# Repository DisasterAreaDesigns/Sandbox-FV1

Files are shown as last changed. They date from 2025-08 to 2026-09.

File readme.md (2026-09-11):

# FV-1 Sandbox
FV-1 Sandbox is a self-contained open-source development platform for the Spin FV-1 digital signal processing (DSP) integrated circuit.  

## Background:
The Spin Semiconductor FV-1 IC was developed by Alesis alumni Keith Barr and Frank Thomson.  It features an integrated architecture with built-in analog-to-digital and digital-to-analog converters, memory, and processing core.  It requires only a few external components to operate, and can run user programs from an inexpensive serial EEPROM.  It has been used in hundreds of different pedals and devices, with many hundreds of thousands of units in service.

## Why Are We Doing This?
The FV-1 has seven built-in programs that cover a wide range of effects, but most designers leverage the custom code capabilities of the chip.  The Fv-1 is programmed in SpinASM, a proprietary assembly language.  Spin provided a free integrated development environment for Windows computers called SpinASM IDE.  This interfaces with a development board fitted with a Cypress PSoC microcontroller functioning as a USB interface.  The IDE allows for code editing, rapid auditioning of DSP algorithms on the development board, and production programming using multi-algorithm .SPJ Spin Project files.  No MacOS or Linux programming tools were made available, and SpinASM also had issues running on newer versions of Windows.  A patch was released to fix compatibility issues under Windows 7, and this version (1.1.31) works with most Windows 10 and Windows 11 systems.  The IDE does also run under Windows for ARM, but support for the PSoC-based development board is broken due to driver issues.

Our intention is to create a complete toolchain that can run on any modern computer that interfaces with a high-quality hardware platform for deploying algorithms.  To this end, we have created an open-source assembler that runs in a web browser and a hardware platform that interfaces with an inexpensive RP2040 microcontroller for programming.  The hardware platform may be assembled without the microcontroller for higher-quantity production use, and the RP2040 programmer may be used in conjunction with either a TagConnect programming cable or pin sockets on the PCB for production programming.

## What Did We Do?
We've been using [asfv1](https://github.com/ndf-zz/asfv1), an open-source assembler for FV-1 designed by Nathan Fraser.  It works great but requires a few steps to deploy as part of a larger toolchain.  It works with Sublime Text or Notepad++ to create a DIY development environment, but it's still a lot of work for a new user.  So we decided to build a one-stop shop!

We patched up some bugs we found, added some quality-of-life improvements, and ported the whole thing from Python to JavaScript so we could run it in a browser.  There's a pretty decent code editor using Monaco, an assembler, and a one-button deployment to the Sandbox hardware.

The hardware is very simple, incorporating a high-quality analog front-end that reduces out-of-band and clock noise from the FV-1.  It's full stereo, features three user potentiometer controls, and two toggle switches for selecting one of six possible algorithms.  It also uses program zero to bypass the effect, allowing stereo switching without any external hardware or relays, albeit at the cost of higher noise floor and a slight delay from the DSP ADC+DAC conversions.

Programming is accomplished using the aforementioned RP2040 board - we've used a Waveshare RP2040 Zero for its compact form factor and handy USB-C port, but clones of this part or other variations may also work.  the RP2040 code is implemented in CircuitPython for ease of deployment and modification.  To program a new algorithm on the Sandbox EEPROM, simply copy an assembled .HEX or .BIN file to the RP2040 CIRCUITPY or SANDBOX removable drive.  Name the program 0.HEX to program algorithm zero, 1.HEX for program 1, and so on.  Adding any other named .BIN or .HEX file will write program #3, which is the program accessed if no toggle switches are assembled to the Sandbox PCBA.

We've also added an FV-1 simulator to the web app.  The assembled program runs through a software model of the chip at its native 32.768 kHz, so you can audition an algorithm on a test tone, an audio file, or live input before you ever program the hardware.  The three pot controls are on screen, and each successful build reloads into the simulator while it plays.  Two indicator lamps follow `REG30` and `REG31`.  The simulator models accumulator saturation and the FV-1's companded delay memory, and its LFO rates and depths follow the equations in Spin's application note AN-0001.  Chorus interpolation is approximated, so always confirm a design on real hardware.

The simulator can also be played from a MIDI controller plugged into your computer.  Press **Enable MIDI** in the simulator panel, allow the browser's MIDI prompt, and pick an input and channel.  `CC50`, `CC51` and `CC52` sweep POT0, POT1 and POT2, and `CC102` switches the effect, with `0-63` bypassed and `64-127` engaged.  MIDI moves the same controls the sliders do, at the full 128 steps a control change carries, so a program cannot tell the difference between a fader and a mouse.  Note that the Sandbox pedal itself has no MIDI input - this drives the simulator only.

The simulator can be watched as well as heard.  **Open register viewer**, under **Debug Tools** in the simulator panel, opens a second window (floating above the editor where the browser allows it, with an **Always on top** switch in its header) showing `ACC`, the audio in and out, the pots, the LFOs and `REG0`-`REG31` as the program runs, each as its S.23 value and the 24-bit word behind it, and named after the `EQU` lines in your source.  Click a register there to plot it over time - an audio-rate signal shows as its envelope and an LFO as its shape.  **ACC trace in editor** writes the accumulator after every instruction at the end of its line, live: a `SKP` says whether it was taken, the lines it jumped over say so, and a line whose result had to be clamped shows how often that happens.  The FV-1 runs every instruction every sample, so one pass is a complete trace and there is nothing to step through to see it.

When there is, the **Debug** section halts the simulator and steps it.  **Halt** freezes the core at the end of the current sample; **Step** runs one instruction, **Sample** runs the rest of the pass, and **Run to line** goes on until that line is next, with the editor following, the trace showing this pass up to the halt, and the register viewer updating on every step.  Breakpoints are conditions rather than places, since a bare line would trip on the first sample: click the margin left of a line number for a line breakpoint and give it a first run or a sample number, or halt on a clip, a `SKP` going one way, or `ACC` or a register crossing a value.  While halted the output is silent and the input is held at the halted sample; **Resume** carries on from wherever the stepping got to.

So it's a web app and a pedal.  Hook 'em up and write some code!

## Running the Assembler Locally
The web app needs to be served over http - opening `Assembler/index.html` directly as a `file://` page will not work.  Browsers block the audio engine the simulator depends on from `file://` origins, and the directory and serial access used to talk to the hardware need a secure context too.  `localhost` counts as secure, so any static file server will do:

```
python3 -m http.server 8000 --directory Assembler
```

Then open <http://localhost:8000> in Chrome or Edge.  If you prefer Node, `npx serve Assembler` works the same way.

Chrome or Edge are required for programming hardware and selecting folders, since Firefox and Safari do not implement the File System Access and Web Serial APIs.  The simulator itself works in any browser with AudioWorklet support, and its MIDI control works in Chrome, Edge and Firefox - Safari has no Web MIDI.

## What's In This Repo?
* **ASFV1 Source:**  copies of the Python source for asfv1, the reference assembler this one is checked against
* **Assembler:**  JavaScript Web Application for assembling FV-1 programs, including an in-browser FV-1 simulator (`fv1-emu.js` / `fv1-sim.js`) with MIDI control (`fv1-midi.js`), a register viewer (`fv1-regs.js`), an ACC trace in the editor (`fv1-trace.js`) and a halt-and-step debugger with conditional breakpoints (`fv1-debug.js`)
* **Firmware**  CircuitPython code for the RP2040 Zero program module
* **spin-test**  Puppeteer scripts and sample FV-1 programs for testing the assembler: `npm run test:roundtrip` for the assembler and simulator as a pair, `npm run test:emu` for the DSP core, `npm run test:midi` for the simulator's MIDI control, and `npm run test:page` for the editor's unsaved-changes guard
* **Hardware**  Schematic and PCB files for Sandbox pedal hardware

## What Can I Do With All This?
We've released this project and all associated tools under the [MIT License.](https://www.tldrlegal.com/license/mit-license)  This means that you can use the tools and information in this repository for anything you want, as long as you inform your users / customers / clients that you got it from us.  You can modify or change anything here to suit your purposes, and you can make products that you sell for profit.  You can even close your sources, so that what's in your product or project is private.  You just have to credit us as shown in our [license file.](https://github.com/DisasterAreaDesigns/Sandbox-FV1/blob/main/LICENSE)  An example of what that looks like can be found in our [Third Party Notices](https://github.com/DisasterAreaDesigns/Sandbox-FV1/blob/main/ThirdPartyNotices.txt) file.

Any projects you create with these tools belong to you.  If you write your own code to process audio with this project, that code is under your copyright and is yours to do with what you wish.  If you use someone else's DSP algorithms, that use will be subject to *their* license terms, and we're not able to help you sort that out.  TL:DR you can do whatever you want with this repo, just give us credit.

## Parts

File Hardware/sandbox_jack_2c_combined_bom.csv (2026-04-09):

Comment | Designator | Footprint | LCSC Part # | Type
 | JP1 | 1X05 |  | THT
DC_TRS | J2 | JACK_DC_PC-MOUNT_2.1MM_NO-KEEPOUT |  | THT
STEREOSW3NOMOUNT | J1 J3 | NEUTRIK-NRJ6HF-NOMOUNT |  | THT

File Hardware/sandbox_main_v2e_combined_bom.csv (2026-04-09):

Comment | Designator | Footprint | LCSC Part # | Type
 | FS | 1X02 |  | THT
 | I2C | 1X04 |  | THT
 | JP1 | 1X07 |  | THT
 | LED1 | DUOLED-C-5MM |  | THT
 | PWR | 1X03 |  | THT
 | SW100 SW101 | 320-916 |  | THT
 | TC1 | TC2030-MCP-NL |  | SMD
0 | R1 | R0805 |  | SMD
0.1uF | C1 C2 C20 C22 C32 | C0805K |  | SMD
0.047uF | C29 C30 | C1206K |  | SMD
1M | R33 R35 R36 R38 | R0805 |  | SMD
1k | R7 R8 | R0805 |  | SMD
1uF | C33 | C0805K |  | SMD
2.2nF | C12 C13 C16 C21 | C0805K |  | SMD
2SK209-GR | Q1 Q2 | SOT-23 |  | SMD
4.7K | R31 | R0805 |  | SMD
10k | R2 R3 R4 R6 R11 R12 R17 R18 R25 R26 R32 R34 R37 | R0805 |  | SMD
10kB | POT0 POT1 POT2 | POT_9MM_PACK_SM |  | THT
10uF | C7 C9 C10 C11 C24 C25 C26 C27 | CT3216 |  | SMD
10uf | C5 C6 | C0805K |  | SMD
15pF | C3 | C0805K |  | SMD
22k | R9 R10 R13 R14 R15 R16 R21 R22 R40 | R0805 |  | SMD
24LC32ASN | IC1 | SO-08 |  | SMD
32.768kHz | X2 | CRYSTAL-SMD-3.2X1.5MM |  | SMD
47pF | C18 C23 | C0805K |  | SMD
47uF | C8 C15 | C1206K |  | SMD
56k | R19 R20 R23 R24 R39 | R0805 |  | SMD
68pF | C17 C19 | C0805K |  | SMD
74HC08 | IC2 | SO14 |  | SMD
74HC4024M | IC6 | SO14 |  | SMD
78L33SMD | VR1 | SO08 |  | SMD
100 | R5 | R0805 |  | SMD
100k | R27 R28 | R0805 |  | SMD
100uF | C4 C14 C31 | C1206K |  | SMD
220uF | C28 | PANASONIC_D |  | SMD
560 | R29 R30 | R0805 |  | SMD
628 | H1 | 628 |  | THT
BAS40 | D1 D2 | SOT23-R |  | SMD
DSIC02LSGET | SW1 | CTS-219-02 |  | SMD
NJM2100 | IC5 | SO08 |  | SMD
SPINFV-1 | IC3 | SOIC-28 |  | SMD
TL072D | IC4 | SO08 |  | SMD

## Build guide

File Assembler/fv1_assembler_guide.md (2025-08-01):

# FV-1 DSP Assembler Web App Guide

## Overview

This web application is a JavaScript port of an assembler for the Spin Semiconductor FV-1 digital signal processor (DSP). The FV-1 is a specialized chip commonly used in guitar effects pedals and audio processing applications. This assembler converts human-readable assembly code into machine code that can run on the FV-1 chip.

## Architecture

The application consists of three main components:

### 1. User Interface (HTML/CSS)
- **Code Editor**: A textarea with line numbers for writing assembly code
- **Options Panel**: Checkboxes for assembly options (clamping, SpinASM compatibility)
- **Control Buttons**: Assemble, Clear, Load File, Download outputs
- **Output Display**: Shows assembled machine code in Intel HEX format
- **Message Area**: Displays warnings and errors

### 2. FV1Assembler Class (JavaScript)
The core assembler implemented as a JavaScript class that handles:
- **Tokenization**: Breaking source code into meaningful symbols
- **Parsing**: Converting tokens into an abstract syntax tree
- **Code Generation**: Converting parsed instructions into machine code
- **Error Handling**: Tracking and reporting syntax/semantic errors

### 3. File I/O System
- **Input**: Load assembly files (.asm, .txt)
- **Output**: Download as Intel HEX (.hex) or binary (.bin) files

## How the Assembler Works

### Phase 1: Tokenization

The `tokenize()` method breaks source code into tokens:

```javascript
// Example: "LDAX ADCL" becomes ["LDAX", "ADCL"]
// "SOF 0.5, -0.2" becomes ["SOF", "0.5", ",", "-0.2"]
```

**Token Types:**
- `MNEMONIC`: Instruction names (LDAX, WRAX, SOF, etc.)
- `ASSEMBLER`: Directives (EQU, MEM)
- `NAME`: Labels and symbols
- `INTEGER`: Whole numbers (decimal, hex with $, binary with %)
- `FLOAT`: Decimal numbers
- `OPERATOR`: Arithmetic and punctuation (+, -, *, /, ,, etc.)
- `LABEL`: Names followed by colons

### Phase 2: Symbol Table Initialization

The assembler pre-populates a symbol table with:
- **Hardware registers**: POT0-POT2, ADCL, ADCR, DACL, DACR
- **General registers**: REG0-REG31
- **LFO references**: SIN0, SIN1, RMP0, RMP1
- **CHO operation types**: RDA, SOF, RDAL
- **Condition codes**: RUN, ZRC, ZRO, GEZ, NEG

### Phase 3: Parsing

The parser uses recursive descent to handle:

#### Expression Parsing
Supports full arithmetic with operator precedence:
- **Bitwise**: `|` (OR), `^` (XOR), `&` (AND)
- **Shift**: `<<`, `>>`
- **Arithmetic**: `+`, `-`, `*`, `/`, `//` (integer division)
- **Power**: `**`
- **Unary**: `-`, `~`, `!`

#### Fixed-Point Number Formats
The FV-1 uses various fixed-point formats:

- **S.10** (11-bit): 1 sign + 10 fractional bits, range -1.0 to ~0.999
- **S.15** (16-bit): 1 sign + 15 fractional bits, range -1.0 to ~0.999
- **S.23** (24-bit): 1 sign + 23 fractional bits, range -1.0 to ~0.999
- **S1.9** (11-bit): 1 sign + 1 integer + 9 fractional bits, range -2.0 to ~1.999
- **S1.14** (16-bit): 1 sign + 1 integer + 14 fractional bits, range -2.0 to ~1.999
- **S4.6** (11-bit): 1 sign + 4 integer + 6 fractional bits, range -16.0 to ~15.98

#### Instruction Parsing
Each instruction type has specific parsing rules:

**Memory Operations:**
```assembly
RDA DELAY, 0.5     ; Read from delay memory with coefficient
WRA DELAY, 0.8     ; Write to delay memory with coefficient
```

**Register Operations:**
```assembly
RDAX POT0, 0.5     ; Read register with multiplication
WRAX DACL, 1.0     ; Write to register with multiplication
```

**Mathematical Operations:**
```assembly
SOF 0.5, 0.1       ; Scale and offset: ACC = ACC * 0.5 + 0.1
LOG 0.8, 0.2       ; Logarithm with scaling
EXP 1.0, 0.0       ; Exponential with scaling
```

### Phase 4: Memory Management

#### Delay Memory Allocation
The `MEM` directive allocates delay memory:
```assembly
MEM DELAY 1024     ; Allocate 1024 samples
; Creates symbols:
;   DELAY   = base address
;   DELAY#  = end address (base + size)
;   DELAY^  = middle address (base + size/2)
```

#### Program Memory
- Maximum 128 instructions (4 bytes each = 512 bytes total)
- Instructions automatically padded to 128 with NOPs

### Phase 5: Code Generation

Each instruction is converted to a 32-bit machine code word:

```javascript
// Example: SOF 0.5, 0.1
// Opcode: 0b01101 (SOF)
// Multiplier: 0.5 * 2^14 = 8192 (S1.14 format)  
// Offset: 0.1 * 2^10 = 102 (S.10 format)
machineCode = 0b01101 | (8192 << 16) | (102 << 5);
```

**Bit Field Layout varies by instruction:**
- Bits 0-4: Opcode
- Bits 5-31: Operands (register addresses, coefficients, etc.)

## Supported Instructions

### Core Instructions

**Accumulator Operations:**
- `LDAX reg` - Load register to accumulator (pseudo for RDFX reg, 0)
- `CLR` - Clear accumulator (pseudo for AND 0)

**Arithmetic:**
- `SOF coeff, offset` - Scale and offset
- `MULX reg` - Multiply by register
- `LOG coeff, offset` - Logarithm
- `EXP coeff, offset` - Exponential

**Logic:**
- `AND mask` - Bitwise AND
- `OR mask` - Bitwise OR  
- `XOR mask` - Bitwise XOR
- `NOT` - Bitwise NOT (pseudo for XOR 0xFFFFFF)

**Register I/O:**
- `RDAX reg, coeff` - Read register with coefficient
- `WRAX reg, coeff` - Write to register with coefficient
- `RDFX reg, coeff` - Read register with coefficient (filtered)
- `WRLX reg, coeff` - Write to register (low shelf)
- `WRHX reg, coeff` - Write to register (high shelf)

**Memory I/O:**
- `RDA addr, coeff` - Read delay memory
- `WRA addr, coeff` - Write delay memory
- `WRAP addr, coeff` - Write delay memory with wrap
- `RMPA coeff` - Ramp delay address

**Control Flow:**
- `SKP condition, target` - Skip instructions conditionally
- `NOP` - No operation (pseudo for SKP 0, 0)

**LFO Control:**
- `WLDS lfo, freq, amp` - Write LFO sine
- `WLDR lfo, freq, amp` - Write LFO ramp
- `CHO type, lfo, flags, coeff` - Chorus/LFO operations
- `JAM lfo` - Reset LFO

### Pseudo-Instructions

Some instructions are implemented as combinations of others:
- `LDAX reg` → `RDFX reg, 0`
- `CLR` → `AND 0`  
- `NOT` → `XOR 0xFFFFFF`
- `NOP` → `SKP 0, 0`
- `ABSA` → `MAXX 0, 0`

## Assembly Options

### Clamp Out-of-Range Values
When enabled, values exceeding format ranges are automatically clamped rather than causing errors:
```javascript
// S.10 range: -1.0 to 0.999
// Input: 1.5 → Clamped to 0.999
// Input: -2.0 → Clamped to -1.0
```

### SpinASM Reals Compatibility
Makes integer literals 1 and 2 treated as floating-point (1.0, 2.0) for compatibility with the original SpinASM assembler.

## Error Handling

The assembler provides detailed error reporting:

### Syntax Errors
- Undefined symbols
- Invalid instruction formats
- Missing operands
- Type mismatches

### Semantic Errors  
- Register numbers out of range (0-63)
- Memory addresses exceeding chip limits
- Skip offsets too large (max 63)
- Delay memory exhaustion

### Warnings
- Value clamping when enabled
- Label redefinition
- Invalid flag combinations

## Output Formats

### Intel HEX Format
Standard format for programming microcontrollers:
```
:04000000018001000E2
:04000400028002000C4
:00000001FF
```
- Each line contains 4 bytes (1 instruction)
- Includes address and checksum
- Terminated with EOF record

### Binary Format
Raw 512-byte binary file containing machine code directly loadable to FV-1.

## Example Programs

### Simple Pass-Through
```assembly
LDAX ADCL        ; Load left input
WRAX DACL, 0     ; Write to left output
LDAX ADCR        ; Load right input  
WRAX DACR, 0     ; Write to right output
```

### Basic Delay/Reverb
```assembly
MEM DELAY 8192   ; Allocate delay memory
LDAX ADCL        ; Load input
WRA DELAY, 0.5   ; Write to delay with feedback
RDA DELAY#, 0.6  ; Read from end of delay
WRAX DACL, 0     ; Output delayed signal
```

### Tremolo Effect
```assembly
WLDS SIN0, 10, 32767    ; Set up LFO
LDAX ADCL               ; Load input
MULX POT0               ; Scale by pot
CHO SOF, SIN0, SIN|REG|COMPC, 0  ; Apply tremolo
WRAX DACR, 0            ; Output
```

## Technical Details

### Memory Layout
- **Program Memory**: 128 × 32-bit instructions (512 bytes)
- **Delay Memory**: 32,767 samples maximum
- **Registers**: 32 general-purpose + special I/O registers

### Number Formats
The assembler automatically converts between decimal and fixed-point:
```javascript
// Input: 0.5
// S1.14: 0.5 × 2^14 = 8192 = 0x2000
// S.10:  0.5 × 2^10 = 512  = 0x200
```

### Symbol Resolution
Two-pass assembly resolves forward references:
1. **First pass**: Parse instructions, build symbol table
2. **Second pass**: Resolve labels, generate machine code

This web application provides a complete development environment for FV-1 programming, making it accessible to create custom audio effects without requiring specialized software installation.

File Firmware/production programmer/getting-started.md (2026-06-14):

# Sandbox-FV1 EEPROM Programmer — Getting Started

This device is a CircuitPython-based programmer for the 24LC32A I2C EEPROM used in
Spin FV-1 effects platforms. You program it by **dragging Intel HEX files onto the
board's USB drive** — no separate software required.

Two files run automatically on the microcontroller:

- `boot.py` — runs once at power-on, sets up the USB drive and device identity.
- `code.py` — the main program, runs continuously after boot.

---

## How `boot.py` works

`boot.py` executes a single time, before `code.py`, each time the board powers up or
resets. It configures how the board appears to your computer:

1. Temporarily remounts the filesystem writable to set the drive label to `SANDBOX-FV1`,
   then remounts it read-only.
2. Enables the USB mass-storage drive so the board shows up as a removable disk.
3. Sets the USB identity to manufacturer **Disaster Area Designs**, product
   **SandboxFV1** (VID `0x1209`, PID `0x3811`).
4. Prints `[SUCCESS] Sandbox-FV1 Boot` to the serial console.

You don't interact with `boot.py` directly. Just know that the drive that appears on
your computer labeled `SANDBOX-FV1` is where your HEX files go.

> Note: because the filesystem is set read-only to the board's own code after boot,
> the *computer* retains write access to the drive — that's what lets you drop files on.

---

## How `code.py` works

`code.py` is an event loop that watches for an EEPROM on the I2C bus and for HEX files
on the drive, then programs the chip. Hardware it drives:

| Pin / Device | Role |
|---|---|
| GP0 (SDA) / GP1 (SCL) | I2C bus to the EEPROM and OLED |
| EEPROM at `0x50` | The 24LC32A target chip (4096 bytes) |
| SSD1306 OLED at `0x3C` | 128×32 two-line status display |
| GP16 WS2812 RGB LED | Status color indicator |
| GP2 | Control/"program" pin, normally HIGH, pulsed LOW after a successful write |
| GP3 | Momentary button (active-low), wakes the OLED screensaver |

### LED status colors

| Color | Meaning |
|---|---|
| Off | Idle / waiting |
| Dim blue | Writing / programming in progress |
| Green | Write successful |
| Red (blinking) | Error or failure |

### What the loop does

1. **Scans for the EEPROM** about once per second. When a chip appears, the OLED shows
   `EEPROM found / Waiting for .hex` and the list of already-processed files is cleared
   so they can be re-flashed. When removed, it shows `No target / Connect EEPROM`.
2. **Looks for `.hex` files** in the drive's root directory (ignoring dotfiles and files
   it has already processed in this session).
3. **Programs each file** it finds, validates it, and writes it to the correct EEPROM
   address.
4. After a successful real write, **pulses GP2 LOW for ~10 ms** to signal the FV-1 to
   reload, then returns to idle.
5. After ~20 seconds of inactivity, a **screensaver** displays a bouncing "FV-1 PROG"
   label on the OLED. Pressing the GP3 button (or any new activity) dismisses it.

> The `SCREENSAVER_TIMEOUT` constant is set to `20` seconds despite a code comment
> that says "5 minutes" — the comment is stale; the actual value is 20 seconds.

---

## HEX file rules (important)

The programmer is strict about file format. Each file is validated before it's written;
if it fails, the OLED shows the reason and the LED goes red.

### Single-slot files

Files **other than `all.hex`** are treated as one FV-1 program slot:

- Must be exactly **129 lines**.
- Must cover address range **0x000–0x1FF** (512 bytes).

The destination address in the EEPROM is chosen by filename:

| Filename | EEPROM start address |
|---|---|
| `0.hex` | `0x0000` |
| `1.hex` | `0x0200` |
| `2.hex` | `0x0400` |
| `3.hex` | `0x0600` |
| `4.hex` | `0x0800` |
| `5.hex` | `0x0A00` |
| `6.hex` | `0x0C00` |
| `7.hex` | `0x0E00` |
| any other name | `0x0600` (default) |

### Full-image file

`all.hex` is a special case that rewrites the whole chip:

- Must be exactly **1025 lines**.
- Must cover address range **0x000–0xFFF** (4096 bytes).
- The entire EEPROM is **cleared to `0xFF` first**, then written from `0x0000`.
- If present, `all.hex` is processed **first and alone** — other HEX files in the same
  drop are skipped that cycle.

### Other behavior

- A **zero-byte HEX file** (no data records) is ignored but still marked as processed —
  no write happens.
- After a successful write, a marker file (e.g. `0.hex.programmed`) is created. This is
  cosmetic; it records that the file was handled.

---

## Quick start

1. Plug the board into USB. A drive labeled **SANDBOX-FV1** appears.
2. Connect the target 24LC32A EEPROM to the I2C pins. The OLED should change from
   `Connect EEPROM` to `EEPROM found / Waiting for .hex`.
3. Drop a correctly-formatted HEX file onto the drive:
   - A single program → name it `0.hex` through `7.hex` for the slot you want.
   - A complete EEPROM image → name it `all.hex`.
4. Watch the OLED and RGB LED:
   - Dim blue = writing, green = done, red = error (check the serial console for detail).
5. On success, GP2 pulses to tell the FV-1 to reload, and the OLED returns to
   `Complete / Waiting for .hex`.

### Seeing serial output

For detailed logs (validation results, byte dumps, errors), open the board's serial
REPL with a terminal such as `screen`, `tio`, PuTTY, or the Mu editor. Every action the
loop takes is printed there.

---

## Troubleshooting

| Symptom | Likely cause |
|---|---|
| OLED says `Connect EEPROM` and stays there | EEPROM not detected on I2C — check wiring/address `0x50` |
| `BAD LINE COUNT` | File isn't 129 lines (single) or 1025 lines (`all.hex`) |
| `BAD ADDR RANGE` | HEX address range doesn't match the expected slot/full ranges |
| Red blinking at startup | I2C bus locked or no EEPROM found during initial scan |
| File dropped but nothing happens | File is a dotfile, zero-byte, or already processed this session (remove/replug EEPROM to reset) |
| OLED shows bouncing "FV-1 PROG" | Screensaver — press the GP3 button to dismiss |

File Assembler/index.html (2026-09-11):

# Sandbox FV-1 Editor

(https://sandboxpedal.com) build 29

## Source Input

Load File...

Or select an example program: Pass-through Delay Chorus Tremolo

Assemble Download HEX Download Binary Download C Headers Save Source...

Clear Editor

## Build Results

No connection

Download to Hardware Clear Hardware

Clear Results

### ▶ Assembly Output

### Confirm Action

Are you sure you want to proceed?

Cancel OK

### Unsaved Changes

You have unsaved changes. What would you like to do?

Cancel Discard Save

### Input Required

Please enter a value:

Cancel OK

MIT License

FV-1 Sandbox Editor by Disaster Area Designs, https://github.com/DisasterAreaDesigns/Sandbox-FV1
Copyright (c) 2025-present by Disaster Area Designs LLC

Uses portions of asfv1 by Nathan Fraser, https://github.com/ndf-zz/asfv1
Copyright (c) 2017-2021 Nathan Fraser

Uses monaco-editor by Microsoft, https://github.com/microsoft/monaco-editor
Copyright (c) 2016-present Microsoft Corporation

THE SOFTWARE IS PROVIDED "AS IS", WITHOUT WARRANTY OF ANY KIND, EXPRESS OR IMPLIED, INCLUDING BUT NOT LIMITED TO THE WARRANTIES OF MERCHANTABILITY, FITNESS FOR A PARTICULAR PURPOSE AND NONINFRINGEMENT. IN NO EVENT SHALL THE AUTHORS OR COPYRIGHT HOLDERS BE LIABLE FOR ANY CLAIM, DAMAGES OR OTHER LIABILITY, WHETHER IN AN ACTION OF CONTRACT, TORT OR OTHERWISE, ARISING FROM, OUT OF OR IN CONNECTION WITH THE SOFTWARE OR THE USE OR OTHER DEALINGS IN THE SOFTWARE.

This web application stores user settings on this computer in local storage. We don't collect information or any personal data from our users.

OPTIONS

INFO

HELP

TEST DRIVE

### Options

#### Editor Options

Select Project Folder No directory selected

Large editor window Show editor mini-map Show full build results Theme:

#### Hardware Options

Select Output Directory No directory selected

Select Serial Port No port selected

Filename / Toggle Position: (none selected)

▲ 2 ▲ ▲ 6 ▼ ● 3 ▲ ● 7 ▼ ▼ 1 ▲ ▼ 5 ▼ 0 (BYPASS) 4 (Not Used) AUTO (#slot)

▲ = switch up, ● = switch mid, ▼ = switch down

AUTO reads ; #slot 5 from a comment in the source, so a program carries its own destination. With no tag it writes 3.hex, the slot a board with no toggles fitted reads.

Keyboard Shortcuts: Ctrl+F Find Ctrl+Shift+F Replace F3 Find Next Alt+A Assemble Alt+D Download to Hardware Alt+C Clear Hardware Alt+P Play / Stop the simulator Keyboard Shortcuts: ⌘+F Find ⌘+⌥+F Replace F3 Find Next ⌃+A Assemble ⌃+D Download to Hardware ⌃+C Clear Hardware ⌃+P Play / Stop the simulator

### FV-1 Simulator

Play Reset

Idle

Program Not loaded

Reset on assemble

#### Outputs

DACL

DACR

#### Clock

Crystal

Rate 32.768 kHz

Max delay 1.00 s, Nyquist 16.4 kHz

The crystal the chip runs from: halve it and every delay and LFO sweep lasts twice as long. Both controls are live.

#### Source

Input

Freq 440 Hz

File No file chosen

#### Pots

POT050%

POT150%

POT250%

POT350%

POT450%

POT550%

Extended set active: POT3-POT5, and 65536 words of delay

#### Indicators

LED10%

LED20%

Lamps follow REG30 and REG31 read as S1.23: 0 is off, 1.0 is full, negative is off.

#### ▶ Debug Tools

#### Registers

Open register viewer

A floating window showing every register as the program runs, named after the editor's EQU lines. Click a register there to plot it over time.

ACC trace in editor

#### Debug

Halt Step Sample

Run to line Go

Running freely

Halt freezes the core where it stands so you can step it, with the editor following. The output is silent while halted.

#### Breakpoints

Add

Click left of a line number to set a line breakpoint. A line on its own halts at once, so give it a condition to halt on something specific.

#### Levels

In -6 dB

Out 0 dB

Bypass (hear dry signal)

#### MIDI Control

Input

Channel

Not connected Enable MIDI

CC50-CC52 sweep the pots, CC60 the clock (4-48 kHz; 83 is stock), and CC102 bypasses below 64.

CC53-CC55 sweep POT3-POT5.

### FV-1 Instruction Set Reference

### Instructions & Help

#### Getting Started

This web application is designed to assemble SpinASM source code into machine instructions for the FV-1 DSP chip. Generated machine code may be saved locally for later use, or sent to a Sandbox FV1 hardware target to hear the results.

- Enter SpinASM source code into the editor area, or select a file or example. Press the Assemble button to verify and assemble the code into a HEX file
- Press the Download HEX to save the resulting HEX file to your local Downloads folder. Check the Build Results for success or error messages.
- Download Binary and Download C Headers output the assembled data in alternate format for use with more advanced applications and are not used with Sandbox FV1 hardware
- When satisfied with your source code, press the Save Source... button to download a local copy.

#### Simulator

The TEST DRIVE tab runs your assembled program through a software FV-1 so you can hear it without hardware.

- Press Assemble, open the TEST DRIVE tab, then press Play. Ctrl+P (Alt+P on Windows) plays and stops from anywhere, including the editor, and opens the tab as it starts.
- Choose a Source: a test tone, noise, a one-second click train, an audio file from your computer, or live input from a microphone or interface. Audio files of any sample rate are resampled to the simulator's clock when loaded.
- The Clock section sets the crystal the simulated chip runs on. Crystal lists the standard parts from 8.192 kHz to 64 kHz; the Rate slider sweeps anything from 4 kHz to 48 kHz and reads Custom when it lands between two named parts. Both are live - the slider can be dragged while a program plays, and CC60 does the same from a MIDI controller. The line underneath gives the two things that follow from the crystal: how much delay time the fixed memory buys you, and where the audio band ends.
- The POT0-POT2 sliders correspond to the three knobs on the Sandbox hardware. A program can name them: put a tag in a comment, like ; #POT0 Delay time, and the labels follow it as you type. Tags are read from the comment part of a line, so they never collide with code, and hovering a renamed pot still shows which one it is.
- The Indicators lamps follow REG30 and REG31. Brightness is the register read as S1.23 - 0 is off, 1.0 is full - and a negative value is off rather than rectified, so a bipolar LFO lights the lamp for half of each cycle unless the program folds it first with sof 0.5, 0.5. The scale is linear on purpose: a program that wants a curve is two instructions from the curve it wants. Name them with ; #LED1 Tempo, as with the pots. Nothing on the FV-1 reserves REG30 or REG31, so a program parking scratch there will light a lamp by accident.
- With Reset on assemble ticked, every successful build is loaded straight into the simulator, so you can edit and re-assemble while it plays.
- Bypass compares against the dry signal, and Reset clears the simulated delay memory.

The simulator models the 24-bit accumulator saturation and the 14-bit companded delay memory that give the FV-1 its character. LFO rates and depths follow the equations in Spin's application note AN-0001. The fractional interpolation inside CHO is approximated, so chorus and flange sound correct but are not sample-identical to hardware. Confirm on the pedal before shipping a design.

Your program is unchanged by the Crystal setting - it still runs 128 instructions per sample - but every delay and LFO sweep scales with the clock, and the fixed delay memory buys you proportionally less time. Halve the clock and every delay lasts twice as long, every LFO sweeps at half the speed, and the audio band ends an octave lower.

The core is clocked separately from the audio graph rather than by it, which is what lets the clock move without stopping anything: sweep the Rate slider mid-program and delay memory keeps its contents, the input keeps playing, and a reverb tail carries across the change instead of being cut off. The conversion between the two clocks band-limits the core's input and output to its own Nyquist, the way the converters on either side of a real FV-1 do, so a low crystal sounds dark rather than aliased.

#### MIDI Control

The simulator can be played from a MIDI controller plugged into your computer. Press Enable MIDI in the TEST DRIVE tab, allow the browser's prompt, then choose an Input and Channel. The dot and the line beside the button show the last message that was accepted, which is the quickest way to tell whether a controller is reaching the page at all.

- CC50, CC51 and CC52 sweep POT0, POT1 and POT2.
- CC60 sweeps the clock across the same 4 kHz to 48 kHz the Rate slider covers - 0 is 4 kHz, 127 is 48 kHz, and the stock 32.768 kHz is around 83. It changes the crystal while the program runs, so an expression pedal on CC60 stretches every delay and sweep in the program without interrupting it.
- CC102 switches the effect: 0-63 bypasses, 64-127 engages.

Nothing here responds to MIDI beat clock. CC60 is the crystal, not tempo sync: the FV-1 has no tempo to lock to, and on hardware changing it means changing the part. A control change with no control behind it is accepted and does nothing. MIDI otherwise moves the same controls the sliders do, at the full 128 steps a control change carries, so a program cannot tell the difference between a fader and a mouse. The chosen input and channel are remembered, and a controller unplugged and plugged back in is picked up again on its own.

Web MIDI needs Chrome, Edge or Firefox - Safari does not implement it. Note that the Sandbox pedal itself has no MIDI input; this drives the simulator only.

#### Watching the Program Run

The simulator can be watched as well as heard. Both of these live under Debug Tools in the TEST DRIVE tab, along with the debugger; click the heading to unfold them.

- Open register viewer opens a second window showing ACC, the audio in and out, the pots, the LFOs and REG0-REG31 as the program runs - each as its S.23 value and the 24-bit word behind it. Registers are named after the EQU lines in your source, so REG5 reads as REG5 feedback. It is a real window: drag it to a second display and leave it there while you edit. In Chrome and Edge it floats above the editor with no address bar; Always on top in its header turns that off for an ordinary window.
- Click a register name in the viewer to plot it over time. The Window menu sets how much time the plot covers, from 64 ms to 16 s. An audio-rate signal shows as its envelope and an LFO as its shape, so a sweep that is too fast, an envelope follower that never settles, or a feedback path ringing up are all visible at a glance.
- ACC trace in editor writes the accumulator after every instruction at the end of its line, live, while the program plays. A SKP line says taken when it jumped, the lines it jumped over say skipped, and a line whose result had to be clamped shows clip with the share of recent samples on which that happened - a line pinned at 100% is saturating, one at 2% is catching peaks. The FV-1 runs every instruction every sample, so one pass is a complete trace and there is nothing to step through to see it.
- The trace belongs to the build the simulator is running. Edit the source and it disappears until you assemble again, rather than drifting onto the wrong lines.

#### Halting and Stepping

The Debug section under Debug Tools stops the simulator where it stands and lets you step it one instruction at a time. Breakpoints only fire while the simulator is running, so assemble and press Play first.

- Halt freezes the core at the end of the current sample. The panel shows where it stopped, a ▶ in the editor's margin marks the next instruction, and every line above it shows the accumulator value it just produced; lines below show … because they have not run yet this sample. If the register viewer is open it shows the halted state too.
- Step runs one instruction. Sample runs the rest of this pass and stops at the top of the next one. Run to line carries on until that line is next, across samples if it has to. Stepping off the last instruction lands on end of sample; one more step starts the next.
- Resume (the Halt button, renamed) carries on from wherever the stepping got to. While halted the output is silent and the input is held at the sample it halted on, so stepping through a delay tail shows what the program does with that one input value rather than continuing the tone.
- Reset, or re-assembling with Reset on assemble ticked, clears a halt: the core that was being stepped no longer exists.

Breakpoints are conditions rather than places. Every instruction runs every sample, so a breakpoint on a line by itself halts on the very next sample - a fraction of a millisecond after you set it. That is fine when the point is to step through the program from there; for anything else, give it a condition. Two ways to set one:

- Click the margin just left of a line number. A red dot appears and the line halts on the next sample. Click again to remove it.
- Use the form under Breakpoints for something more specific. Pick a kind, fill in the fields, press Add:
- Line with first run halts only on sample 0, before skp run has started skipping - the way to inspect initialisation code such as a wlds. With on sample # it halts on exactly that sample: 32768 is one second in at the stock crystal.
- Clip halts the first time a line's result is clamped. Leave the line blank for any line.
- SKP halts when a branch goes the way you name, taken or not taken.
- ACC and Register halt when the value crosses a threshold - DACL > 0.9, REG5 < -0.5. They fire when the condition becomes true, not while it stays true, so a register sitting above its threshold does not halt again on the instruction after every resume. Registers are listed with their EQU names.

Each breakpoint in the list has a checkbox to leave it set but quiet, and ✕ to remove it. Click one to jump to its line. A breakpoint on a line with no instruction - a comment, a blank line, an EQU - is shown greyed until a build gives that line one. Breakpoints follow their lines as you edit above them, and are matched to the build again on every assemble.

#### Extended Instruction Set

This program carries #extended, which turns on an instruction set beyond the FV-1's own - the same instruction set with the constraints that made sense in silicon in 1999 lifted. An FV-1 does not implement any of it, so an extended build is not a program the Sandbox pedal can run. Delete the line and the extra instructions become errors again, which is the point: without it, this assembler produces exactly the bytes it always did.

- Delay memory is 65536 words rather than 32768 - two seconds at the standard crystal instead of one - and MEM may allocate all of it.
- POT3, POT4 and POT5 join the three the FV-1 has. The simulator shows sliders for them as soon as the source carries the pragma - you need the slider while you are writing the program that reads it, not after - and CC53, CC54 and CC55 sweep them.
- RMPAX reads ADDR_PTR as ACC[22:7] instead of ACC[23:8], keeping the accumulator's sign out of the address so wrax addr_ptr / rmpax sweeps the whole tank with no seam. Plain RMPA still works, and still reaches only the low 32K.
- RAND loads a register with a uniform random sample - rand reg0, 0.002 is a dither, rand reg0, 1.0 is full scale - without spending four or five instructions on an LFSR.
- SIN2, SIN3, RMP2 and RMP3 double the LFOs, with their eight registers at 0x08-0x0f.
- A program may be 256 instructions rather than 128. The FV-1 runs all 128 every sample whether they are used or not, so on the chip the length is the time budget; off it a skip skips and the padding is never reached, so what is left of 128 is a container. The image only grows if the program does - 128 instructions or fewer still assemble to the same 512 bytes - and a skip still reaches 63 instructions, which is now less than a quarter of a program.

The EXTENDED section of the instruction reference has the detail, and appears alongside this one. The simulator runs all of it, so an extended program can be auditioned here before it goes anywhere near hardware - but Download to Hardware will ask before writing one to a Sandbox pedal, since what is in that pedal is an FV-1.

#### Connecting to Hardware

Connect your Sandbox FV1 pedal to your computer using a suitable USB cable. A new removable drive labeled SANDBOX-FV1 should appear.

- Open the Hardware Options section to Select Output Directory button to specify the path to your Sandbox FV1 (typically /SANDBOX-FV1).
- Use the Filename / Toggle Position buttons to select the destination slot on your hardware device
- Press the Download to Hardware button to save your algorithm to the Sandbox FV1 hardware unit

#### Troubleshooting

Errors and warnings will appear in the Build Results window and are often helpful for troubleshooting. Scroll up to the top to see previous messages

- Error information not helpful - use Editor Options - Show full build results to see more detailed info
- File transfer problems - ensure proper directory permissions
- Assembly errors - check syntax and register usage
- Connection issues - verify USB cable and folder selection

#### What do these Options do?

These are some settings that change various editor settings

### Editor Options

- Select Project Folder: Choose path to save HEX, binary, header, and source files
- Large editor window: Expands editor text area to show more instructions
- Theme: Use light, dark, or system color theme
- Show editor mini-map: Show a small navigation map in editor
- Show full build results: Show complete debug information in Build Results window

### Hardware Options

- Select Output Directory: Specify the folder location of your Sandbox FV hardware (typically /SANDBOX-FV1)
- Filename / Toggle Position: Select the destination slot on your hardware device

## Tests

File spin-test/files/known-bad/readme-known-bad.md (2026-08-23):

# Known bad programs

These are not assembler bugs. Both programs contain invalid SpinASM and
will not assemble with any FV-1 assembler. They are kept here for
reference and moved out of `files/` so they do not show up as failures
in the test run - `loadTestProgramsFromDirectory()` in `spin-test/test.js`
does not recurse into subdirectories.

## faux-phaser.spn

Line 23:

    CHO RDAL,4

The FV-1 has four LFOs, selected as 0-3 (SIN0, SIN1, RMP0, RMP1). There
is no LFO 4. Line 20 of the same program correctly uses `CHO RDAL,0`.

## shimmer-2.spn

Line 139, and again at 156, 166, 201 and 217:

    mulx kd

`kd` is declared on line 36 as a coefficient, not a register:

    equ kd -0.5

`MULX` multiplies the accumulator by the contents of a register and takes
a register address (0-63) as its operand. Passing -0.5 truncates to -1,
which is out of range. Multiplying by a constant is `SOF -0.5, 0`.

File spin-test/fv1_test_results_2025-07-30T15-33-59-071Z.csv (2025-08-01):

Program Name | Has Errors | Error Message | Assembly Successful | Timestamp | Source Code Preview | Raw Output Preview
3K_V1_0_Hall | false |  | true | 2025-07-30T15:12:58.712Z | ;Hall. ;Pot0 = predelay 0-100ms. ;Pot1 = reverb time ;Pot2 = damping mem pdel 32... | FV-1 DSP Assembler build 05 Input Source Code Select an example program... Simple Pass-through Simple Delay Simple Chorus 1 2 3 4 5 6 7 8 9 10 11 12 13 14 15 16 17 18 19 20 21 22 23 24 25 26 27 28 29 30 31 32 33 34 35 36 37 38 39 40 41 42 43 44 45 46 47 48 49 50 51 52 53 54 55 56 57 58 59 60 61 62 63 64 65 66 67 68 69 70 71 72 73 74 75 76 77 78 79 80 81 82 83 84 85 86 87 88 89 90 91 92 93 94 95 96 97 98 99 100 101 102 103 104 105 106 107 108 109 110 111 112 113 114 115 116 117 118 119 120 121
3K_V1_1_Room | false |  | true | 2025-07-30T15:13:09.450Z | ;Room. ;Pot0 = predelay 0-100ms. ;Pot1 = reverb time ;Pot2 = damping mem pdel 32... | FV-1 DSP Assembler build 05 Input Source Code Select an example program... Simple Pass-through Simple Delay Simple Chorus 1 2 3 4 5 6 7 8 9 10 11 12 13 14 15 16 17 18 19 20 21 22 23 24 25 26 27 28 29 30 31 32 33 34 35 36 37 38 39 40 41 42 43 44 45 46 47 48 49 50 51 52 53 54 55 56 57 58 59 60 61 62 63 64 65 66 67 68 69 70 71 72 73 74 75 76 77 78 79 80 81 82 83 84 85 86 87 88 89 90 91 92 93 94 95 96 97 98 99 100 101 102 103 104 105 106 107 108 109 110 111 112 113 114 115 116 117 118 119 120 121
3K_V1_2_PLATE | false |  | true | 2025-07-30T15:13:18.237Z | ;Plate program. ;pot0 = predelay (0-127) ;pot1 = RT (0-127) ;pot2 = damping (0-127) ... | FV-1 DSP Assembler build 05 Input Source Code Select an example program... Simple Pass-through Simple Delay Simple Chorus 1 2 3 4 5 6 7 8 9 10 11 12 13 14 15 16 17 18 19 20 21 22 23 24 25 26 27 28 29 30 31 32 33 34 35 36 37 38 39 40 41 42 43 44 45 46 47 48 49 50 51 52 53 54 55 56 57 58 59 60 61 62 63 64 65 66 67 68 69 70 71 72 73 74 75 76 77 78 79 80 81 82 83 84 85 86 87 88 89 90 91 92 93 94 95 96 97 98 99 100 101 102 103 104 105 106 107 108 109 110 111 112 113 114 115 116 117 118 119 120 121
3K_V1_3_GATED | false |  | true | 2025-07-30T15:13:27.042Z | ;gated reverb. ;Pot0 = predelay 0-100ms. ;Pot1 = gate time ;Pot2 = damping ;Imme... | FV-1 DSP Assembler build 05 Input Source Code Select an example program... Simple Pass-through Simple Delay Simple Chorus 1 2 3 4 5 6 7 8 9 10 11 12 13 14 15 16 17 18 19 20 21 22 23 24 25 26 27 28 29 30 31 32 33 34 35 36 37 38 39 40 41 42 43 44 45 46 47 48 49 50 51 52 53 54 55 56 57 58 59 60 61 62 63 64 65 66 67 68 69 70 71 72 73 74 75 76 77 78 79 80 81 82 83 84 85 86 87 88 89 90 91 92 93 94 95 96 97 98 99 100 101 102 103 104 105 106 107 108 109 110 111 112 113 114 115 116 117 118 119 120 121
3K_V1_4_ECHO-REV | false |  | true | 2025-07-30T15:13:34.306Z | ;ECHO+REVERB. ;Pot0 = delay 100-500ms. ;Pot1 = repeat ;Pot2 = reverb (fixed parameters)... | FV-1 DSP Assembler build 05 Input Source Code Select an example program... Simple Pass-through Simple Delay Simple Chorus 1 2 3 4 5 6 7 8 9 10 11 12 13 14 15 16 17 18 19 20 21 22 23 24 25 26 27 28 29 30 31 32 33 34 35 36 37 38 39 40 41 42 43 44 45 46 47 48 49 50 51 52 53 54 55 56 57 58 59 60 61 62 63 64 65 66 67 68 69 70 71 72 73 74 75 76 77 78 79 80 81 82 83 84 85 86 87 88 89 90 91 92 93 94 95 96 97 98 99 100 101 102 103 104 105 106 107 108 109 110 111 112 113 114 115 116 117 118 119 120 121
3K_V1_5_STECHO-REV | false |  | true | 2025-07-30T15:13:41.727Z | ;ECHO+REVERB. ;Pot0 = delay 100-500ms. ;Pot1 = repeat ;Pot2 = reverb (fixed parameters)... | FV-1 DSP Assembler build 05 Input Source Code Select an example program... Simple Pass-through Simple Delay Simple Chorus 1 2 3 4 5 6 7 8 9 10 11 12 13 14 15 16 17 18 19 20 21 22 23 24 25 26 27 28 29 30 31 32 33 34 35 36 37 38 39 40 41 42 43 44 45 46 47 48 49 50 51 52 53 54 55 56 57 58 59 60 61 62 63 64 65 66 67 68 69 70 71 72 73 74 75 76 77 78 79 80 81 82 83 84 85 86 87 88 89 90 91 92 93 94 95 96 97 98 99 100 101 102 103 104 105 106 107 108 109 110 111 112 113 114 115 116 117 118 119 120 121
3K_V1_6_CHOR-REV | false |  | true | 2025-07-30T15:13:50.150Z | ;CHORUS+REVERB. ;Pot0 = chorus width ;Pot1 = sweep rate ;Pot2 = reverb (fixed parameter... | FV-1 DSP Assembler build 05 Input Source Code Select an example program... Simple Pass-through Simple Delay Simple Chorus 1 2 3 4 5 6 7 8 9 10 11 12 13 14 15 16 17 18 19 20 21 22 23 24 25 26 27 28 29 30 31 32 33 34 35 36 37 38 39 40 41 42 43 44 45 46 47 48 49 50 51 52 53 54 55 56 57 58 59 60 61 62 63 64 65 66 67 68 69 70 71 72 73 74 75 76 77 78 79 80 81 82 83 84 85 86 87 88 89 90 91 92 93 94 95 96 97 98 99 100 101 102 103 104 105 106 107 108 109 110 111 112 113 114 115 116 117 118 119 120 121
3K_V1_7_FLANGE | false |  | true | 2025-07-30T15:13:57.934Z | ;FLANGE ;mono effect, searing regeneration. ;Pot0 = delay ;Pot1 = sweep rate ;Po... | FV-1 DSP Assembler build 05 Input Source Code Select an example program... Simple Pass-through Simple Delay Simple Chorus 1 2 3 4 5 6 7 8 9 10 11 12 13 14 15 16 17 18 19 20 21 22 23 24 25 26 27 28 29 30 31 32 33 34 35 36 37 38 39 40 41 42 43 44 45 46 47 48 49 50 51 52 53 54 55 56 57 58 59 60 61 62 63 64 65 66 67 68 69 70 71 72 73 74 75 76 77 78 79 80 81 82 83 84 85 86 87 88 89 90 91 92 93 94 95 96 97 98 99 100 101 102 103 104 105 106 107 108 109 110 111 112 113 114 115 116 117 118 119 120 121
8_seconds_delay | false |  | true | 2025-07-30T15:14:04.471Z | ; This example code delays an input by eight seconds. ; It inteleaves the signal 8 ways in a single... | FV-1 DSP Assembler build 05 Input Source Code Select an example program... Simple Pass-through Simple Delay Simple Chorus 1 2 3 4 5 6 7 8 9 10 11 12 13 14 15 16 17 18 19 20 21 22 23 24 25 26 27 28 29 30 31 32 33 34 35 36 37 38 39 40 41 42 43 44 45 46 47 48 49 50 51 52 53 54 55 56 57 58 59 60 61 62 63 64 65 66 67 68 69 70 71 72 73 74 75 76 77 78 79 80 81 82 83 84 85 Clamp out-of-range values SpinASM reals (2 → 2.0, 1 → 1.0) Assemble Clear Assembly Save Source... Assembly successful! Output S
ARPEGGIO | true | Errors: | Error on line 419: Expected EQU or MEM but got NAME "label_note2" | Error on line 435: Expected EQU or MEM but got LABEL "label_note7" | false | 2025-07-30T15:14:14.944Z | ; Ascending Major Chord Arpeggio by Alex Lawrow ; ============================================= ; ... | FV-1 DSP Assembler build 05 Input Source Code Select an example program... Simple Pass-through Simple Delay Simple Chorus 1 2 3 4 5 6 7 8 9 10 11 12 13 14 15 16 17 18 19 20 21 22 23 24 25 26 27 28 29 30 31 32 33 34 35 36 37 38 39 40 41 42 43 44 45 46 47 48 49 50 51 52 53 54 55 56 57 58 59 60 61 62 63 64 65 66 67 68 69 70 71 72 73 74 75 76 77 78 79 80 81 82 83 84 85 86 87 88 89 90 91 92 93 94 95 96 97 98 99 100 101 102 103 104 105 106 107 108 109 110 111 112 113 114 115 116 117 118 119 120 121
ARPEGGIO_MINOR | true | Errors: | Error on line 419: Expected EQU or MEM but got NAME "label_note2" | Error on line 435: Expected EQU or MEM but got LABEL "label_note7" | false | 2025-07-30T15:14:24.913Z | ; Ascending Minor Chord Arpeggio by Alex Lawrow ; ============================================= ; ... | FV-1 DSP Assembler build 05 Input Source Code Select an example program... Simple Pass-through Simple Delay Simple Chorus 1 2 3 4 5 6 7 8 9 10 11 12 13 14 15 16 17 18 19 20 21 22 23 24 25 26 27 28 29 30 31 32 33 34 35 36 37 38 39 40 41 42 43 44 45 46 47 48 49 50 51 52 53 54 55 56 57 58 59 60 61 62 63 64 65 66 67 68 69 70 71 72 73 74 75 76 77 78 79 80 81 82 83 84 85 86 87 88 89 90 91 92 93 94 95 96 97 98 99 100 101 102 103 104 105 106 107 108 109 110 111 112 113 114 115 116 117 118 119 120 121
GA_DEMO_CHORUS | false |  | true | 2025-07-30T15:14:32.170Z | ;GA_DEMO Chorus ;Pot0 = Reverb level ;Pot1 = Rate ;pot2 = Effect level ;memory d... | FV-1 DSP Assembler build 05 Input Source Code Select an example program... Simple Pass-through Simple Delay Simple Chorus 1 2 3 4 5 6 7 8 9 10 11 12 13 14 15 16 17 18 19 20 21 22 23 24 25 26 27 28 29 30 31 32 33 34 35 36 37 38 39 40 41 42 43 44 45 46 47 48 49 50 51 52 53 54 55 56 57 58 59 60 61 62 63 64 65 66 67 68 69 70 71 72 73 74 75 76 77 78 79 80 81 82 83 84 85 86 87 88 89 90 91 92 93 94 95 96 97 98 99 100 101 102 103 104 105 106 107 108 109 110 111 112 113 114 115 116 117 118 119 120 121
GA_DEMO_ECHO | false |  | true | 2025-07-30T15:14:39.358Z | ;GA_DEMO Echo ;Pot0 = Reverb level ;Pot1 = delay ;pot2 = Echo level ;memory decl... | FV-1 DSP Assembler build 05 Input Source Code Select an example program... Simple Pass-through Simple Delay Simple Chorus 1 2 3 4 5 6 7 8 9 10 11 12 13 14 15 16 17 18 19 20 21 22 23 24 25 26 27 28 29 30 31 32 33 34 35 36 37 38 39 40 41 42 43 44 45 46 47 48 49 50 51 52 53 54 55 56 57 58 59 60 61 62 63 64 65 66 67 68 69 70 71 72 73 74 75 76 77 78 79 80 81 82 83 84 85 86 87 88 89 90 91 92 93 94 95 96 97 98 99 100 101 102 103 104 105 106 107 108 109 110 111 112 113 114 115 116 117 118 119 120 121
GA_DEMO_ECHO_RPT | false |  | true | 2025-07-30T15:14:46.456Z | ;GA_DEMO Echo with repeats ;Pot0 = Reverb level ;Pot1 = Delay ;pot2 = Echo level ... | FV-1 DSP Assembler build 05 Input Source Code Select an example program... Simple Pass-through Simple Delay Simple Chorus 1 2 3 4 5 6 7 8 9 10 11 12 13 14 15 16 17 18 19 20 21 22 23 24 25 26 27 28 29 30 31 32 33 34 35 36 37 38 39 40 41 42 43 44 45 46 47 48 49 50 51 52 53 54 55 56 57 58 59 60 61 62 63 64 65 66 67 68 69 70 71 72 73 74 75 76 77 78 79 80 81 82 83 84 85 86 87 88 89 90 91 92 93 94 95 96 97 98 99 100 101 102 103 104 105 106 107 108 109 110 111 112 113 114 115 116 117 118 119 120 121
GA_DEMO_FLANGE | false |  | true | 2025-07-30T15:14:54.279Z | ;GA_DEMO Flanger ;Pot0 = Reverb level ;Pot1 = Flange rate ;pot2 = Effect level w/ feedb... | FV-1 DSP Assembler build 05 Input Source Code Select an example program... Simple Pass-through Simple Delay Simple Chorus 1 2 3 4 5 6 7 8 9 10 11 12 13 14 15 16 17 18 19 20 21 22 23 24 25 26 27 28 29 30 31 32 33 34 35 36 37 38 39 40 41 42 43 44 45 46 47 48 49 50 51 52 53 54 55 56 57 58 59 60 61 62 63 64 65 66 67 68 69 70 71 72 73 74 75 76 77 78 79 80 81 82 83 84 85 86 87 88 89 90 91 92 93 94 95 96 97 98 99 100 101 102 103 104 105 106 107 108 109 110 111 112 113 114 115 116 117 118 119 120 121
GA_DEMO_PHASE | false |  | true | 2025-07-30T15:15:02.817Z | ;GA_DEMO Phase shifter ;Pot0 = Reverb level ;Pot1 = Phase rate ;pot2 = Sweep width ... | FV-1 DSP Assembler build 05 Input Source Code Select an example program... Simple Pass-through Simple Delay Simple Chorus 1 2 3 4 5 6 7 8 9 10 11 12 13 14 15 16 17 18 19 20 21 22 23 24 25 26 27 28 29 30 31 32 33 34 35 36 37 38 39 40 41 42 43 44 45 46 47 48 49 50 51 52 53 54 55 56 57 58 59 60 61 62 63 64 65 66 67 68 69 70 71 72 73 74 75 76 77 78 79 80 81 82 83 84 85 86 87 88 89 90 91 92 93 94 95 96 97 98 99 100 101 102 103 104 105 106 107 108 109 110 111 112 113 114 115 116 117 118 119 120 121
GA_DEMO_TREM | false |  | true | 2025-07-30T15:15:09.935Z | ;GA_DEMO Tremelo ;Pot0 = Reverb level ;Pot1 = Tremelo rate ;pot2 = Effect level ;mem... | FV-1 DSP Assembler build 05 Input Source Code Select an example program... Simple Pass-through Simple Delay Simple Chorus 1 2 3 4 5 6 7 8 9 10 11 12 13 14 15 16 17 18 19 20 21 22 23 24 25 26 27 28 29 30 31 32 33 34 35 36 37 38 39 40 41 42 43 44 45 46 47 48 49 50 51 52 53 54 55 56 57 58 59 60 61 62 63 64 65 66 67 68 69 70 71 72 73 74 75 76 77 78 79 80 81 82 83 84 85 86 87 88 89 90 91 92 93 94 95 96 97 98 99 100 101 102 103 104 105 106 107 108 109 110 111 112 113 114 115 116 117 118 119 120 121
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

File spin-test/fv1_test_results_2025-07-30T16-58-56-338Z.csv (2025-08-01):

Program Name | Has Errors | Error Message | Assembly Successful | Timestamp | Source Code Preview | Raw Output Preview
"3K_V1_0_Hall" | false | "" | true | 2025-07-30T16:40:00.895Z | ";Hall.
;Pot0 = predelay 0-100ms.
;Pot1 = reverb time
;Pot2 = damping
mem pdel 32..." | "FV-1 DSP Assembler build 05
Input Source Code
Select an example program...
Simple Pass-through
Simple Delay
Simple Chorus
1
2
3
4
5
6
7
8
9
10
11
12
13
14
15
16
17
18
19
20
21
22
23
24
25
26
27
28
29
30
31
32
33
34
35
36
37
38
39
40
41
42
43
44
45
46
47
48
49
50
51
52
53
54
55
56
57
58
59
60
61
62
63
64
65
66
67
68
69
70
71
72
73
74
75
76
77
78
79
80
81
82
83
84
85
86
87
88
89
90
91
92
93
94
95
96
97
98
99
100
101
102
103
104
105
106
107
108
109
110
111
112
113
114
115
116
117
118
119
120
121
"
"3K_V1_1_Room" | false | "" | true | 2025-07-30T16:40:08.039Z | ";Room.
;Pot0 = predelay 0-100ms.
;Pot1 = reverb time
;Pot2 = damping
mem pdel 32..." | "FV-1 DSP Assembler build 05
Input Source Code
Select an example program...
Simple Pass-through
Simple Delay
Simple Chorus
1
2
3
4
5
6
7
8
9
10
11
12
13
14
15
16
17
18
19
20
21
22
23
24
25
26
27
28
29
30
31
32
33
34
35
36
37
38
39
40
41
42
43
44
45
46
47
48
49
50
51
52
53
54
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

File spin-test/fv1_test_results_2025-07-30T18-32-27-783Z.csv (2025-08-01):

Program Name | Has Errors | Error Message | Assembly Successful | Timestamp | Source Code Preview | Raw Output Preview
"3K_V1_0_Hall" | false | "" | true | 2025-07-30T18:13:29.124Z | ";Hall.
;Pot0 = predelay 0-100ms.
;Pot1 = reverb time
;Pot2 = damping
mem pdel 32..." | "FV-1 DSP Assembler build 06
Input Source Code
Select an example program...
Simple Pass-through
Simple Delay
Simple Chorus
1
2
3
4
5
6
7
8
9
10
11
12
13
14
15
16
17
18
19
20
21
22
23
24
25
26
27
28
29
30
31
32
33
34
35
36
37
38
39
40
41
42
43
44
45
46
47
48
49
50
51
52
53
54
55
56
57
58
59
60
61
62
63
64
65
66
67
68
69
70
71
72
73
74
75
76
77
78
79
80
81
82
83
84
85
86
87
88
89
90
91
92
93
94
95
96
97
98
99
100
101
102
103
104
105
106
107
108
109
110
111
112
113
114
115
116
117
118
119
120
121
"
"3K_V1_1_Room" | false | "" | true | 2025-07-30T18:13:36.384Z | ";Room.
;Pot0 = predelay 0-100ms.
;Pot1 = reverb time
;Pot2 = damping
mem pdel 32..." | "FV-1 DSP Assembler build 06
Input Source Code
Select an example program...
Simple Pass-through
Simple Delay
Simple Chorus
1
2
3
4
5
6
7
8
9
10
11
12
13
14
15
16
17
18
19
20
21
22
23
24
25
26
27
28
29
30
31
32
33
34
35
36
37
38
39
40
41
42
43
44
45
46
47
48
49
50
51
52
53
54
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

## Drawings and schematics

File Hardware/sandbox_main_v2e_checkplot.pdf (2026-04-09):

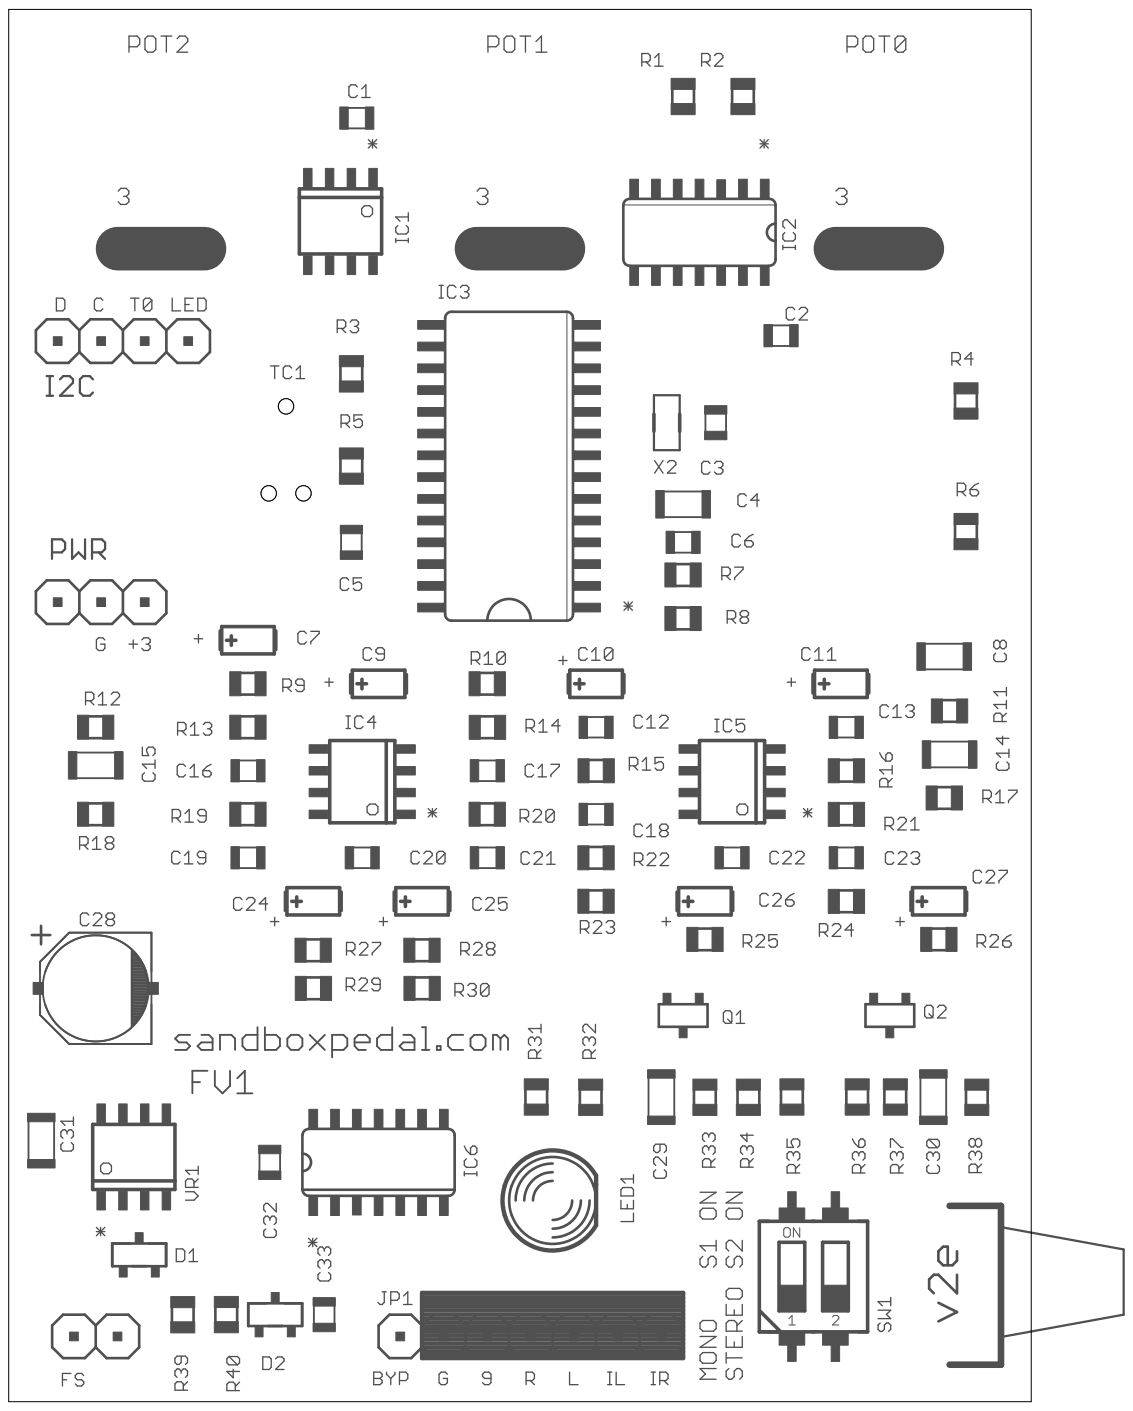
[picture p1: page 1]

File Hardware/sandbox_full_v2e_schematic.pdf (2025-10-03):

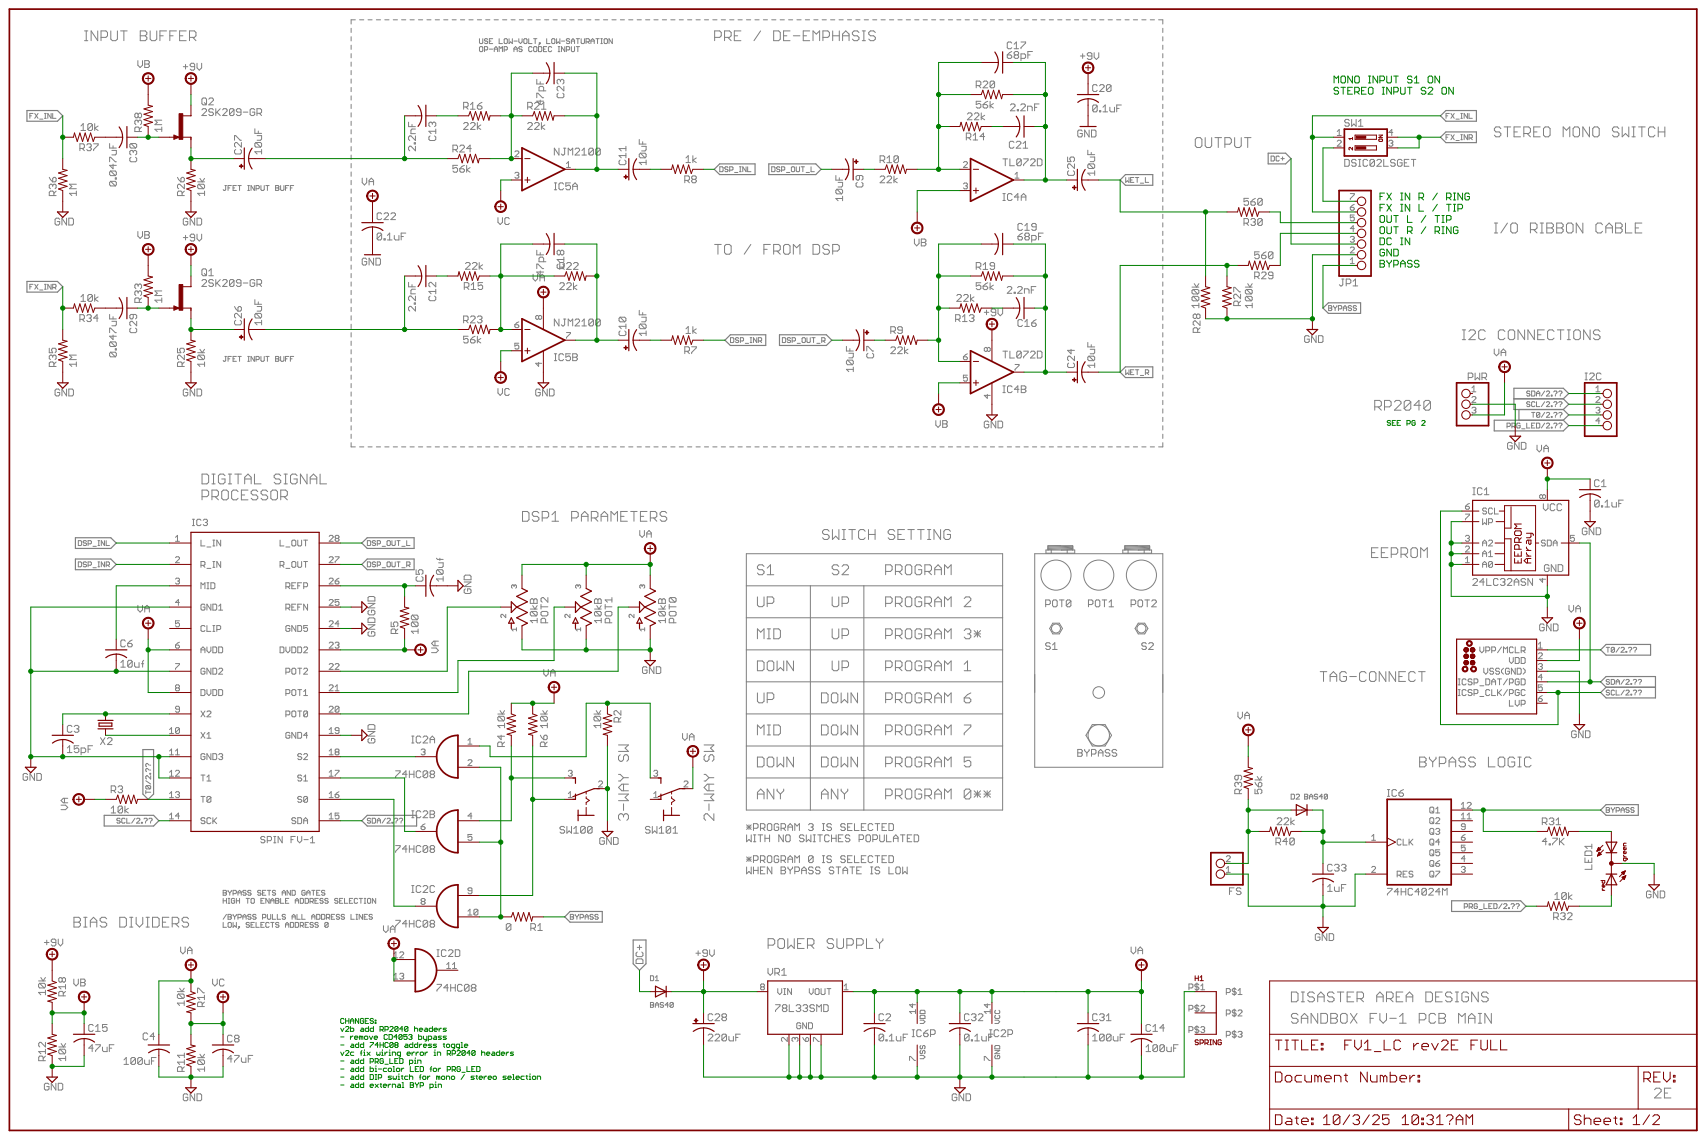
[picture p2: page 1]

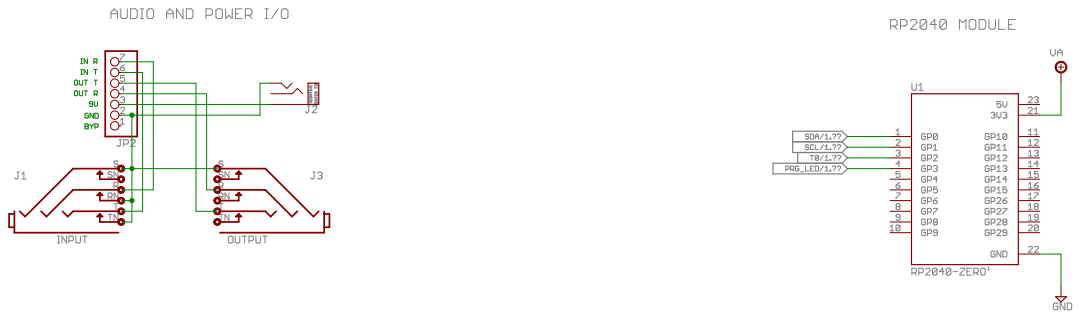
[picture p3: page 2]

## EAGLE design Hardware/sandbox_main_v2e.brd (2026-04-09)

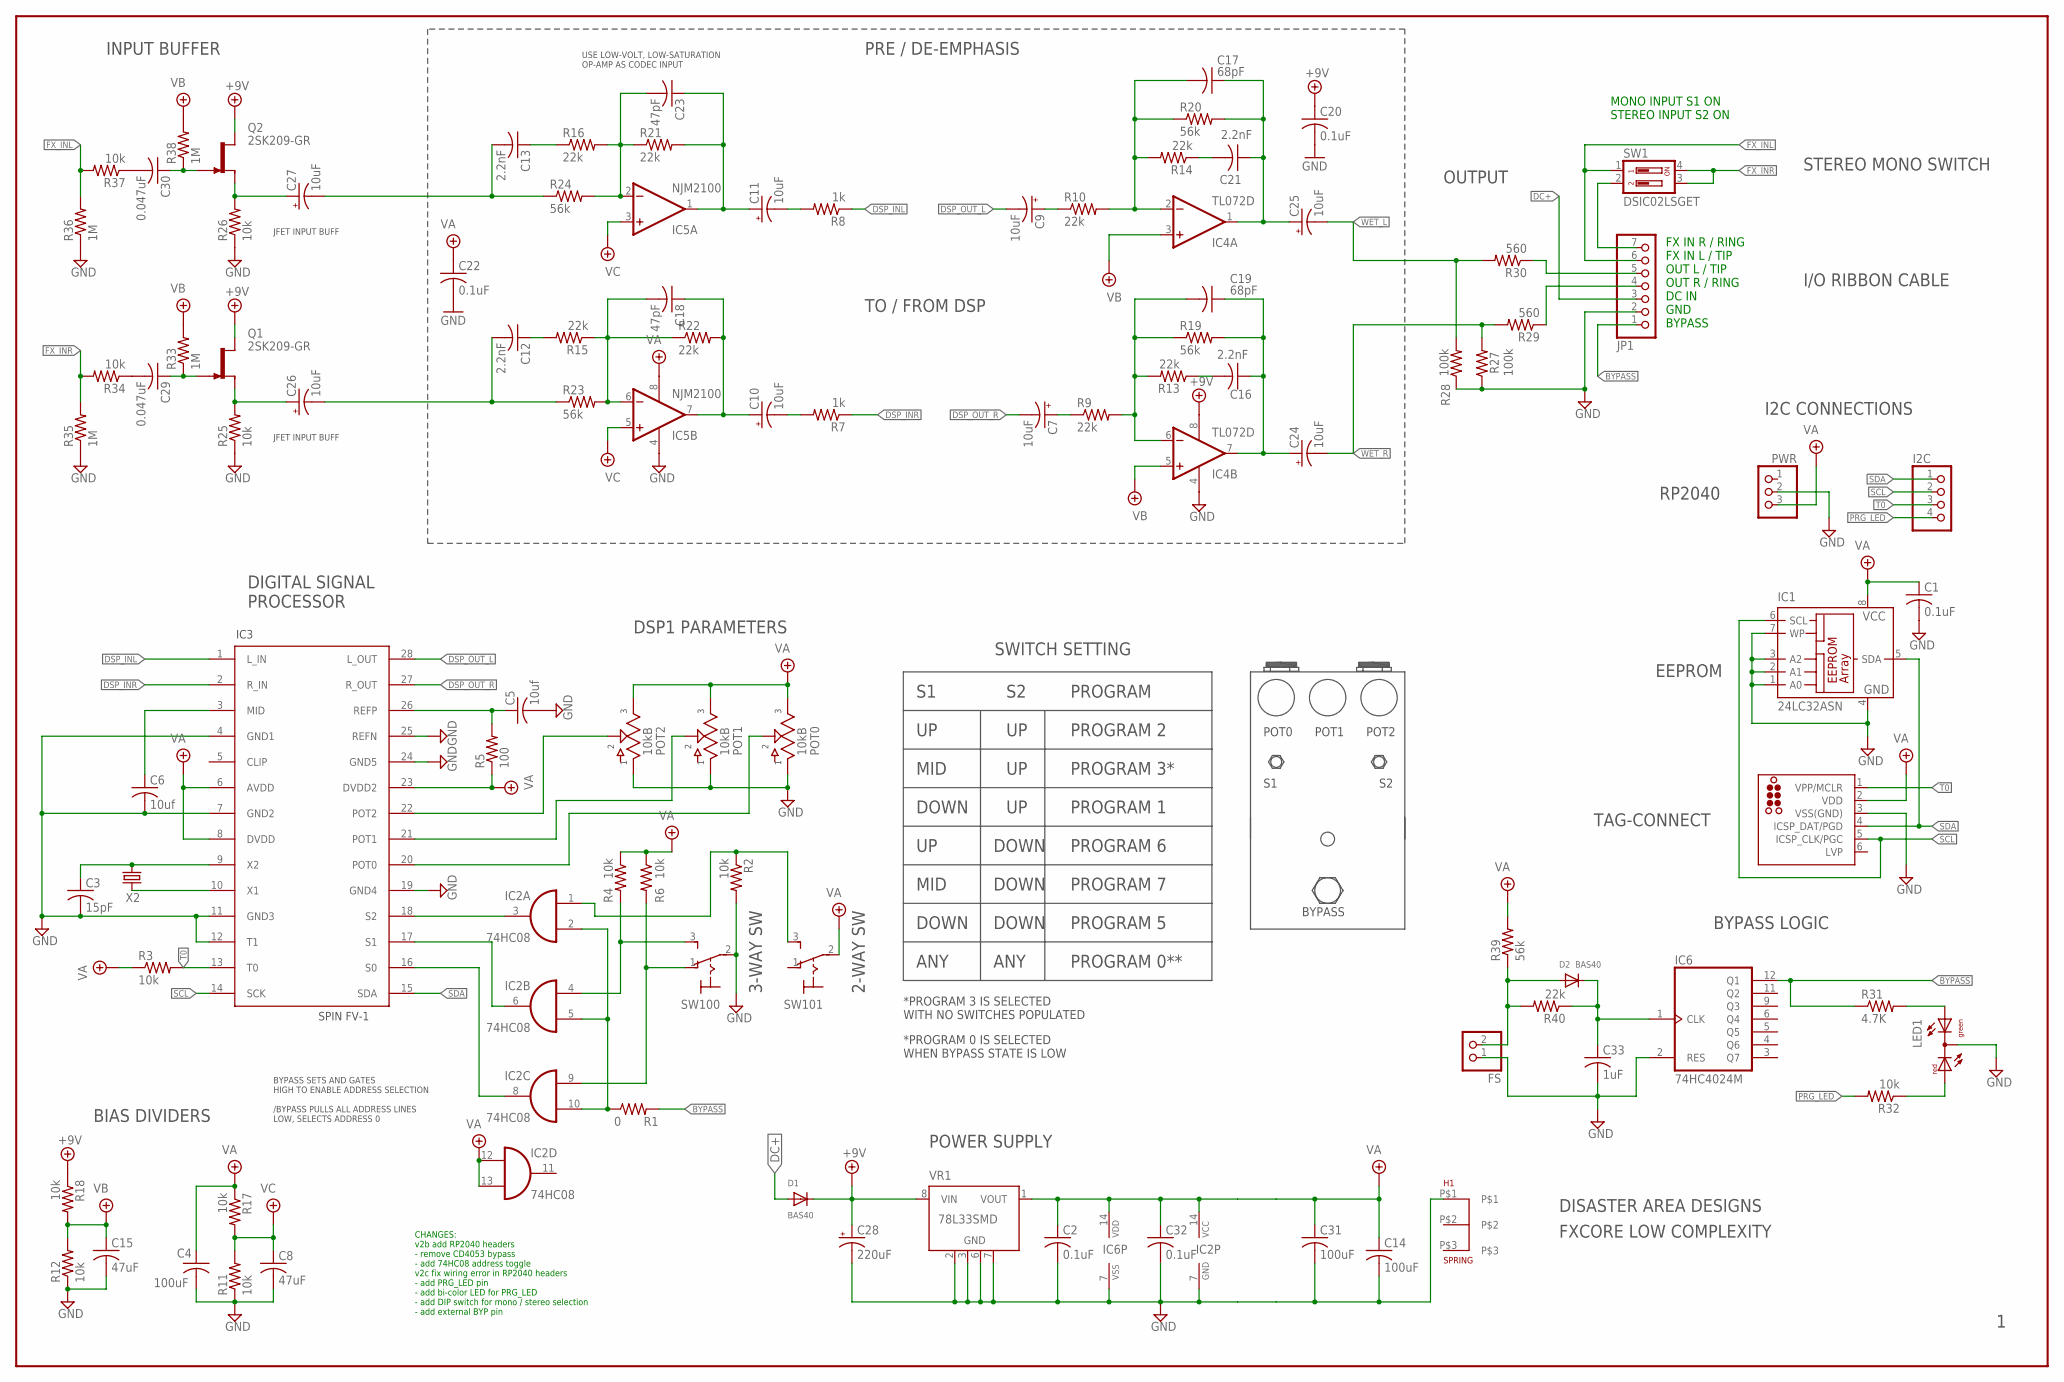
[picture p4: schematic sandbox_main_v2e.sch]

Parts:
C1, C2, C20, C22, C32: 0.1uF; C0805K
C3: 15pF; C0805K
C4, C14, C31: 100uF; C1206K
C5, C6: 10uf; C0805K
C7, C9, C10, C11, C24, C25, C26, C27: 10uF; CT3216
C8, C15: 47uF; C1206K
C12, C13, C16, C21: 2.2nF; C0805K
C17, C19: 68pF; C0805K
C18, C23: 47pF; C0805K
C28: 220uF; PANASONIC_D
C29, C30: 0.047uF; C1206K
C33: 1uF; C0805K
D1, D2: BAS40; SOT23-R
FS: PINHD-1X2; 1X02
H1: 628
I2C: PINHD-1X4; 1X04
IC1: 24LC32ASN; SO-08
IC2: 74HC08; SO14
IC3: SPINFV-1; SOIC-28
IC4: TL072D; SO08
IC5: NJM2100; SO08
IC6: 74HC4024M; SO14
JP1: PINHD-1X7; 1X07
LED1: DUOLED-RG-C; DUOLED-C-5MM
POT0, POT1, POT2: 10kB; POT_9MM_PACK_SM
PWR: PINHD-1X3; 1X03
Q1, Q2: 2SK209-GR; SOT-23
R1: 0; R0805
R2, R3, R4, R6, R11, R12, R17, R18, R25, R26, R32, R34, R37: 10k; R0805
R5: 100; R0805
R7, R8: 1k; R0805
R9, R10, R13, R14, R15, R16, R21, R22, R40: 22k; R0805
R19, R20, R23, R24, R39: 56k; R0805
R27, R28: 100k; R0805
R29, R30: 560; R0805
R31: 4.7K; R0805
R33, R35, R36, R38: 1M; R0805
SW1: DSIC02LSGET; CTS-219-02
SW100, SW101: 320-916
TC1: TC2030_ICSP-MCP-NL; TC2030-MCP-NL
VR1: 78L33SMD; SO08
X2: 32.768kHz; CRYSTAL-SMD-3.2X1.5MM

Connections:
+9V: C20.1, C28.+, D1.3 (C), IC4.8 (V+), Q1.2 (D), Q2.2 (D), R18.1, VR1.8 (VIN)
BYPASS: IC6.12 (Q1), JP1.1, R1.2, R31.1
BYPASS_IC: IC2.2 (I1), IC2.5 (I1), IC2.10 (I1), R1.1
DC+: D1.1 (A), JP1.3
DSP_INL: IC3.1 (L_IN), R8.1
DSP_INR: IC3.2 (R_IN), R7.1
DSP_OUT_L: C9.-, IC3.28 (L_OUT)
DSP_OUT_R: C7.-, IC3.27 (R_OUT)
FX_INL: JP1.6, R36.2, R37.2, SW1.1
FX_INR: R34.2, R35.2, SW1.3, SW1.4
GND: C1.2, C2.2, C3.2, C4.2, C5.2, C6.2, C8.2, C14.2, C15.2, C20.2, C22.2, C28.-, C31.2, C32.2, C33.2, FS.1, H1.P$1, IC1.1 (A0), IC1.2 (A1), IC1.3 (A2), IC1.4 (GND), IC1.7 (WP), IC2.7 (GND), IC3.4 (GND1), IC3.7 (GND2), IC3.11 (GND3), IC3.12 (T1), IC3.19 (GND4), IC3.24 (GND5), IC3.25 (REFN), IC4.4 (V-), IC5.4 (V-), IC6.2 (RES), IC6.7 (VSS), JP1.2, LED1.C, POT0.P$1, POT1.P$1, POT2.P$1, PWR.2, R2.2, R11.1, R12.1, R25.1, R26.1, R27.1, R28.1, R35.1, R36.1, SW100.2, TC1.3 (VSS(GND)), VR1.2 (GND), VR1.3 (GND), VR1.6 (GND), VR1.7 (GND)
unnamed: IC3.10 (X1), X2.P$1 (1)
unnamed: IC2.3 (O), IC3.18 (S2)
unnamed: C29.1, Q1.3 (G), R33.1
unnamed: IC2.6 (O), IC3.17 (S1)
unnamed: C29.2, R34.1
unnamed: IC2.8 (O), IC3.16 (S0)
unnamed: C11.+, C23.1, IC5.1 (OUT), R21.2
unnamed: C23.2, IC5.2 (-IN), R16.2, R21.1, R24.2
unnamed: C12.2, C26.-, R23.1
unnamed: C12.1, R15.2
unnamed: LED1.AR, R32.1
unnamed: JP1.7, SW1.2
unnamed: C13.1, R16.1
unnamed: C5.1, IC3.26 (REFP), R5.2
unnamed: C13.2, C27.-, R24.1
unnamed: C10.-, R7.2
unnamed: C6.1, IC3.3 (MID)
unnamed: C18.2, IC5.6 (-IN), R15.1, R22.1, R23.2
unnamed: C10.+, C18.1, IC5.7 (OUT), R22.2
unnamed: C17.2, IC4.2 (-IN), R10.2, R14.2, R20.1
unnamed: C11.-, R8.2
unnamed: C19.2, IC4.6 (-IN), R9.2, R13.2, R19.1
unnamed: C30.2, R37.1
unnamed: C7.+, R9.1
unnamed: C16.2, R13.1
unnamed: C16.1, C19.1, C24.+, IC4.7 (OUT), R19.2
unnamed: C9.+, R10.1
unnamed: JP1.5, R30.1
unnamed: C21.2, R14.1
unnamed: C17.1, C21.1, C25.+, IC4.1 (OUT), R20.2
unnamed: JP1.4, R29.1
unnamed: C33.1, D2.3 (C), IC6.1 (CLK), R40.1
unnamed: D2.1 (A), FS.2, R39.1, R40.2
unnamed: LED1.AX (AG), R31.2
unnamed: C3.1, IC3.9 (X2), X2.P$2 (2)
unnamed: C26.+, Q1.1 (S), R25.2
unnamed: C27.+, Q2.1 (S), R26.2
unnamed: C30.1, Q2.3 (G), R38.1
P0: IC3.20 (POT0), POT0.P$2
P1: IC3.21 (POT1), POT1.P$2
P2: IC3.22 (POT2), POT2.P$2
PRG_LED: I2C.4, R32.2
S0: IC2.9 (I0), R6.2, SW100.1 (O)
S1: IC2.4 (I0), R4.2, SW100.3 (S)
S2: IC2.1 (I0), R2.1, SW101.3 (S)
SCL: I2C.2, IC1.6 (SCL), IC3.14 (SCK), TC1.5 (ICSP_CLK/PGC)
SDA: I2C.1, IC1.5 (SDA), IC3.15 (SDA), TC1.4 (ICSP_DAT/PGD)
T0: I2C.3, IC3.13 (T0), R3.2, TC1.1 (VPP/MCLR)
VA: C1.1, C2.1, C4.1, C14.1, C22.1, C31.1, C32.1, IC1.8 (VCC), IC2.12 (I0), IC2.13 (I1), IC2.14 (VCC), IC3.6 (AVDD), IC3.8 (DVDD), IC3.23 (DVDD2), IC5.8 (V+), IC6.14 (VDD), POT0.P$3, POT1.P$3, POT2.P$3, PWR.3, R3.1, R4.1, R5.1, R6.1, R17.1, R39.2, SW101.2, TC1.2 (VDD), VR1.1 (VOUT)
VB: C15.1, IC4.3 (+IN), IC4.5 (+IN), R12.2, R18.2, R33.2, R38.2
VC: C8.1, IC5.3 (+IN), IC5.5 (+IN), R11.2, R17.2
WET_L: C25.-, R28.2, R30.2
WET_R: C24.-, R27.2, R29.2

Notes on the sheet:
POWER SUPPLY
DIGITAL SIGNAL PROCESSOR
INPUT BUFFER
FXCORE LOW COMPLEXITY
DSP1 PARAMETERS
3-WAY SW
DISASTER AREA DESIGNS
OUTPUT
POT2
POT1
POT0
BYPASS
BIAS DIVIDERS
SWITCH SETTING
MID
DOWN
PROGRAM 3*
PROGRAM 2
PROGRAM 1
PRE / DE-EMPHASIS
BYPASS LOGIC
USE LOW-VOLT, LOW-SATURATION OP-AMP AS CODEC INPUT
JFET INPUT BUFF
FX IN R / RING FX IN L / TIP OUT L / TIP OUT R / RING DC IN GND BYPASS
PROGRAM 7
PROGRAM 6
PROGRAM 5
PROGRAM
*PROGRAM 3 IS SELECTED WITH NO SWITCHES POPULATED
2-WAY SW
I2C CONNECTIONS
BYPASS SETS AND GATES HIGH TO ENABLE ADDRESS SELECTION /BYPASS PULLS ALL ADDRESS LINES LOW, SELECTS ADDRESS 0
CHANGES: v2b add RP2040 headers - remove CD4053 bypass - add 74HC08 address toggle v2c fix wiring error in RP2040 headers - add PRG_LED pin - add bi-color LED for PRG_LED - add DIP switch for mono / stereo selection - add external BYP pin
ANY
PROGRAM 0**
*PROGRAM 0 IS SELECTED WHEN BYPASS STATE IS LOW
MONO INPUT S1 ON STEREO INPUT S2 ON
SPIN FV-1
IC3
I/O RIBBON CABLE

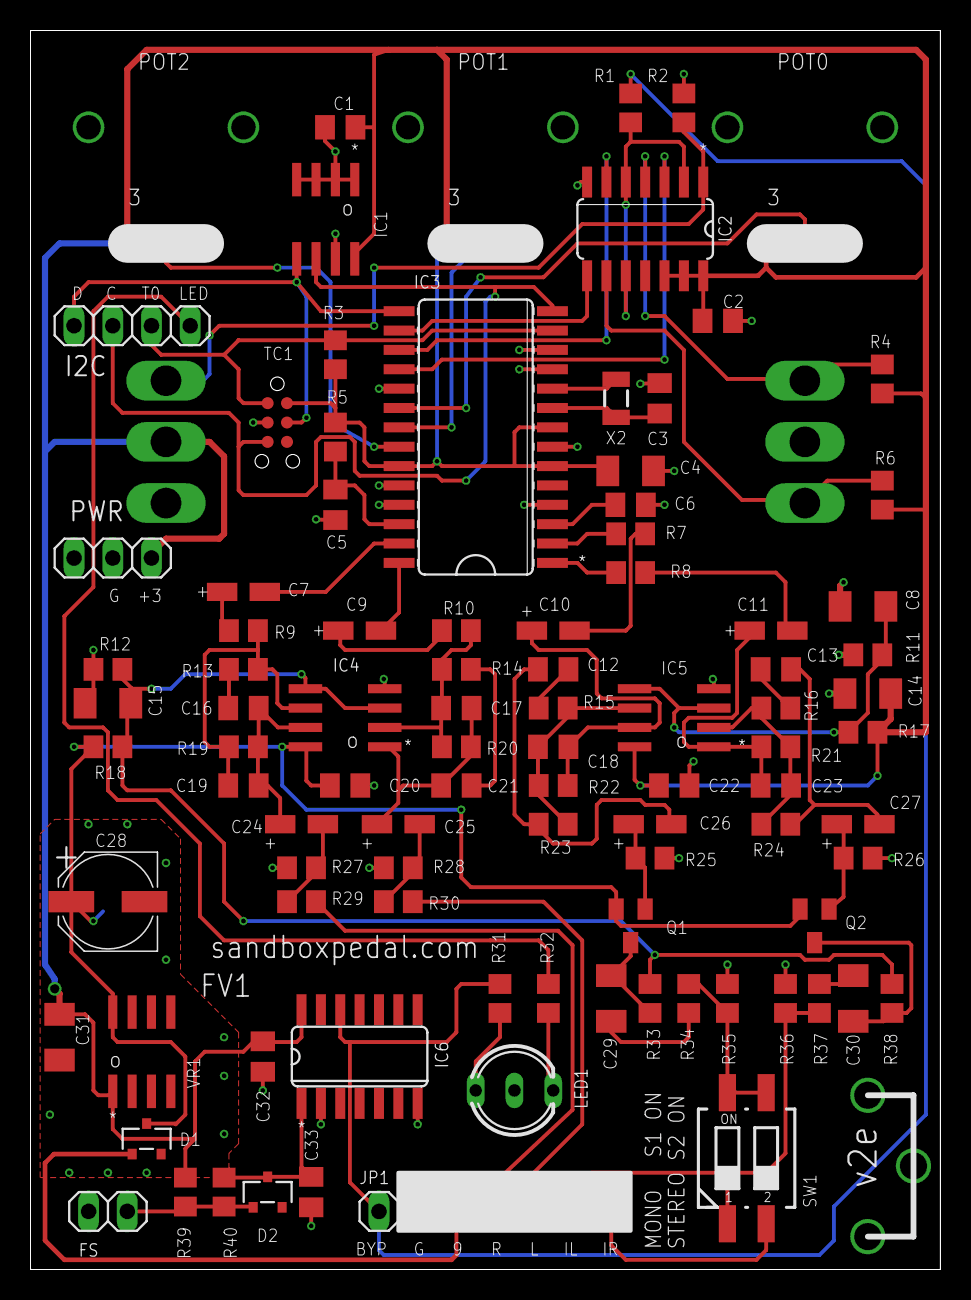
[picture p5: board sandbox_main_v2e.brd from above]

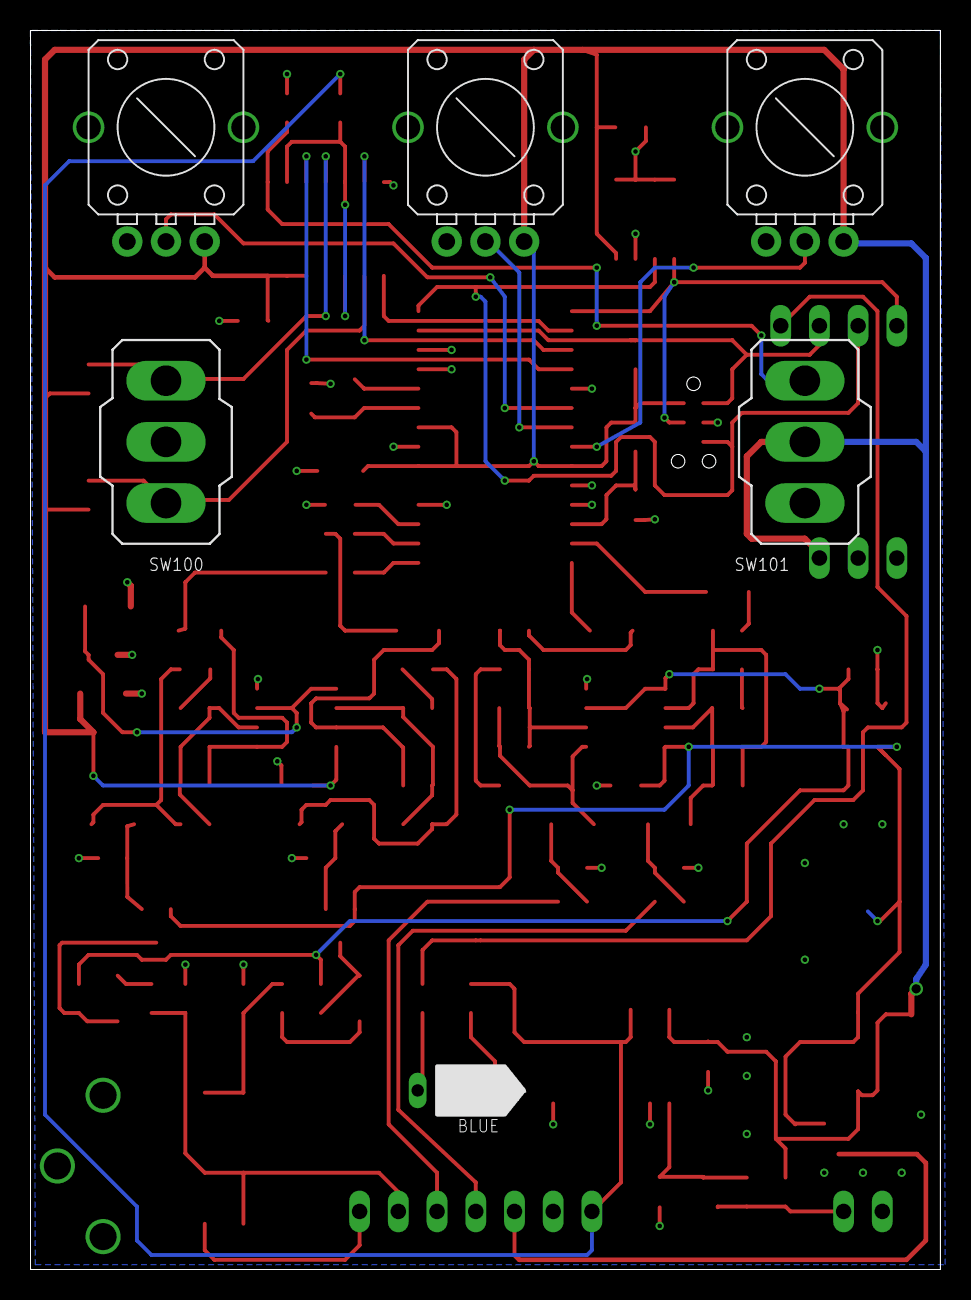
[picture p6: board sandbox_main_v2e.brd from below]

Board: 2 copper layers, 59.7 x 81.3 mm, 98 parts (2 on the bottom side), 64 nets.

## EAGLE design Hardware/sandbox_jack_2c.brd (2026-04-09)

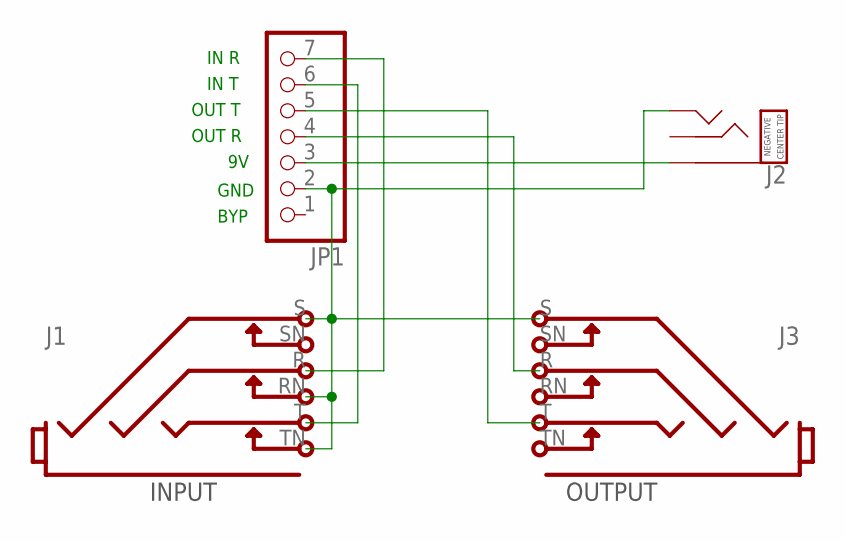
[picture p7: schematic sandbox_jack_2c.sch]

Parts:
J1, J3: STEREOSW3NOMOUNT; NEUTRIK-NRJ6HF-NOMOUNT
J2: DC_TRS; JACK_DC_PC-MOUNT_2.1MM_NO-KEEPOUT
JP1: PINHD-1X7; 1X07

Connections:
JACK_GND: J1.RN, J1.S, J1.TN, J2.3 (GND), J3.S, JP1.2
unnamed: J1.R, JP1.7
unnamed: J2.1 (PWR), JP1.3
unnamed: J1.T, JP1.6
unnamed: J3.T, JP1.5
unnamed: J3.R, JP1.4

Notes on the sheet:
INPUT
OUTPUT
GND
OUT T
IN T
OUT R
IN R
BYP

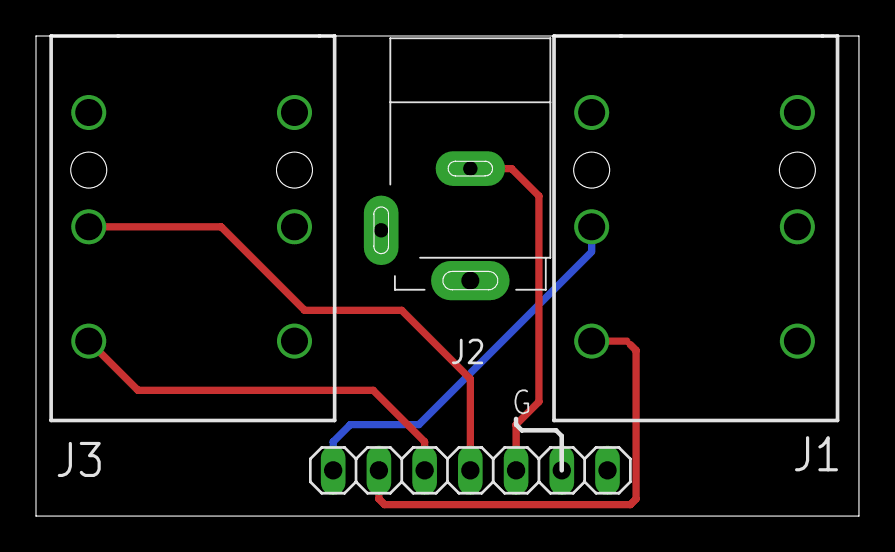
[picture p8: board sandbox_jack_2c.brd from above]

Board: 2 copper layers, 45.7 x 26.7 mm, 4 parts (0 on the bottom side), 6 nets.

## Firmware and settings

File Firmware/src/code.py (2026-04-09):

import os
import time
import board
import busio
import digitalio
import supervisor
import neopixel

# Set up I2C bus on GP0 (SDA) and GP1 (SCL)
i2c = busio.I2C(scl=board.GP1, sda=board.GP0)

# Set up control pin (GP2) - keep HIGH by default, toggle LOW only during programming
control_pin = digitalio.DigitalInOut(board.GP2)
control_pin.direction = digitalio.Direction.OUTPUT
control_pin.value = True  # Keep high by default

# Set up LED pin for user notifications
led_pin = digitalio.DigitalInOut(board.GP3)
led_pin.direction = digitalio.Direction.OUTPUT
led_pin.value = False # turn off by default

# Set up WS2812 RGB LED on GP16
pixel = neopixel.NeoPixel(board.GP16, 1, brightness=1.0, auto_write=True, pixel_order='GRB')

# RGB Color definitions - solid colors only
COLOR_OFF = (0, 0, 0)       # Off
COLOR_RED = (255, 0, 0)     # Red for uploading
COLOR_GREEN = (0, 255, 0)   # Green for success
COLOR_BLUE = (0, 0, 255)    # Blue for idle state
COLOR_DIM_BLUE = (0, 0, 8)  # Very dim blue for programming

# EEPROM address
EEPROM_ADDR = 0x50

# File to EEPROM address mapping
FILE_ADDRESS_MAP = {
    "0.hex": 0x0000,
    "1.hex": 0x0200,
    "2.hex": 0x0400,
    "3.hex": 0x0600,
    "4.hex": 0x0800,
    "5.hex": 0x0A00,
    "6.hex": 0x0C00,
    "7.hex": 0x0E00,
    "all.hex": 0x0000  # Special case: write entire EEPROM starting from beginning
}

# Default start address for other filenames
DEFAULT_START_ADDR = 0x0600

# We'll use the normal REPL for output
def print_serial(message):
    """Print to the REPL"""
    print(message)

def set_led_color(color):
    """Set the WS2812 LED color"""
    pixel[0] = color

def set_status_led(state):
    """Set the status LED (GP3) on/off"""
    led_pin.value = state
    
def blink_led_once(color, duration=0.2):
    """Blink both LEDs once quickly with specified color"""
    set_led_color(color)
    set_status_led(True)
    time.sleep(duration)
    set_led_color(COLOR_OFF)
    set_status_led(False)
    time.sleep(duration)

def blink_led_pattern(color, on_time=0.1, off_time=0.1, count=3):
    """Blink both LEDs in a pattern with specified color"""
    for _ in range(count):
        set_led_color(color)
        set_status_led(True)
        time.sleep(on_time)
        set_led_color(COLOR_OFF)
        set_status_led(False)
        time.sleep(off_time)

def parse_hex_line(line):
    """Parse a single line of Intel HEX format"""
    if not line.startswith(':'):
        return None, None, None, []
    
    # Remove the leading ':' and strip whitespace/newlines
    data = line.strip()[1:]
    
    try:
        # Get basic parameters
        byte_count = int(data[0:2], 16)
        address = (int(data[2:4], 16) << 8) + int(data[4:6], 16)
        record_type = int(data[6:8], 16)
        
        # Extract the data bytes
        byte_data = []
        for i in range(byte_count):
            pos = 8 + (i * 2)
            if pos + 2 <= len(data):
                byte_data.append(int(data[pos:pos+2], 16))
        
        return byte_count, address, record_type, byte_data
    
    except Exception as e:
        print_serial("Error parsing line: " + str(e))
        return None, None, None, []

def write_eeprom_page(eeprom_address, page_address, data):
    """Write a page of data to the EEPROM (max 32 bytes per page)"""
    # Create the I2C write buffer
    buffer = bytearray(2 + len(data))
    buffer[0] = (page_address >> 8) & 0xFF  # High byte of address
    buffer[1] = page_address & 0xFF         # Low byte of address
    buffer[2:] = data                       # Data bytes
    
    # Write to the EEPROM
    try:
        i2c.try_lock()
        i2c.writeto(eeprom_address, buffer)
        i2c.unlock()
        # Wait for write cycle to complete (6ms is sufficient for 24LC32A)
        time.sleep(0.006)  # 6ms
        
        return True
    except Exception as e:
        print_serial("EEPROM write error: " + str(e))
        try:
            i2c.unlock()  # Make sure to unlock even if there's an error
        except:
            pass
        return False

def read_eeprom(eeprom_address, start_address, num_bytes):
    """Read bytes from the EEPROM"""
    # Set the address pointer
    addr_buffer = bytearray(2)
    addr_buffer[0] = (start_address >> 8) & 0xFF  # High byte of address
    addr_buffer[1] = start_address & 0xFF         # Low byte of address
    
    try:
        i2c.try_lock()
        i2c.writeto(eeprom_address, addr_buffer)
        
        # Read the data
        result = bytearray(num_bytes)
        i2c.readfrom_into(eeprom_address, result)
        i2c.unlock()
        return result
    except Exception as e:
        print_serial("EEPROM read error: " + str(e))
        try:
            i2c.unlock()  # Make sure to unlock even if there's an error
        except:
            pass
        return None

def clear_entire_eeprom():
    """Clear the entire EEPROM by writing 0xFF to all locations"""
    print_serial("Clearing entire EEPROM (writing 0xFF to all locations)...")
    
    # For 24LC32A: 4096 bytes (0x0000 to 0x0FFF)
    eeprom_size = 4096
    page_size = 32
    
    # Create a page of 0xFF bytes
    clear_data = bytearray([0xFF] * page_size)
    
    for addr in range(0, eeprom_size, page_size):
        print_serial("Clearing page at address 0x{:04X}".format(addr))
        result = write_eeprom_page(EEPROM_ADDR, addr, clear_data)
        
        if not result:
            print_serial("Error clearing page at address 0x{:04X}".format(addr))
            return False
    
    print_serial("EEPROM cleared successfully")
    return True

def process_and_program_hex_file(filename):
    """Process a HEX file and program the EEPROM"""
    all_bytes = []
    line_count = 0
    min_addr = None
    max_addr = None
    
    # Turn off LEDs while processing files
    set_led_color(COLOR_OFF)
    set_status_led(False)
    
    try:
        # Open and parse the HEX file - first pass to validate
        with open(filename, "r") as f:
            for line in f:
                line = line.strip()
                if not line:
                    continue
                line_count += 1
                
                byte_count, address, record_type, data = parse_hex_line(line)
                
                # Skip invalid lines
                if byte_count is None:
                    continue
                
                # Data record - track address range
                if record_type == 0:
                    if min_addr is None:
                        min_addr = address
                        max_addr = address + len(data) - 1
                    else:
                        min_addr = min(min_addr, address)
                        max_addr = max(max_addr, address + len(data) - 1)
                
                # End of file record
                elif record_type == 1:
                    break
        
        # Second pass - actually extract the data first to check for zero-byte files
        with open(filename, "r") as f:
            for line in f:
                byte_count, address, record_type, data = parse_hex_line(line)
                
                # Skip invalid lines
                if byte_count is None:
                    continue
                
                # Data record
                if record_type == 0:
                    all_bytes.extend(data)
                
                # End of file record
                elif record_type == 1:
                    break
        
        # Check if the hex file contained any data - do this BEFORE validation
        if len(all_bytes) == 0:
            print_serial("Ignoring zero-byte hex file: {}".format(filename))
            set_led_color(COLOR_OFF)
            set_status_led(False)
            return True  # Return True so file gets marked as processed
        
        # Determine expected parameters based on filename
        base_filename = filename.split('/')[-1]
        
        if base_filename == "all.hex":
            expected_lines = 1025
            expected_min_addr = 0x000
            expected_max_addr = 0xFFF
        else:
            expected_lines = 129
            expected_min_addr = 0x000
            expected_max_addr = 0x1FF
        
        # Validate line count
        if line_count != expected_lines:
            print_serial("ERROR: {} must have exactly {} lines, but has {} lines".format(base_filename, expected_lines, line_count))
            set_led_color(COLOR_RED)
            set_status_led(True)
            return False
        
        # Validate address range
        if min_addr != expected_min_addr or max_addr != expected_max_addr:
            print_serial("ERROR: {} must have address range 0x{:03X}-0x{:03X}, but has 0x{:03X}-0x{:03X}".format(
                base_filename, expected_min_addr, expected_max_addr, min_addr or 0, max_addr or 0))
            set_led_color(COLOR_RED)
            set_status_led(True)
            return False
        
        print_serial("Validation passed: {} lines, address range 0x{:03X}-0x{:03X}".format(line_count, min_addr, max_addr))
        
        # Determine start address based on filename
        if base_filename in FILE_ADDRESS_MAP:
            start_address = FILE_ADDRESS_MAP[base_filename]
        else:
            start_address = DEFAULT_START_ADDR
        
        print_serial("Using start address: 0x{:04X} for file: {}".format(start_address, base_filename))
        print_serial("File contains {} bytes of data".format(len(all_bytes)))
        
        # Special handling for all.hex - clear EEPROM first
        if base_filename == "all.hex":
            print_serial("Processing all.hex - will clear entire EEPROM first")
            if not clear_entire_eeprom():
                print_serial("Failed to clear EEPROM for all.hex")
                set_led_color(COLOR_RED)
                set_status_led(True)
                return False
        
        # Program the EEPROM in pages (32 bytes per page for 24LC32A)
        total_bytes = len(all_bytes)
        page_size = 32
        
        print_serial("Programming EEPROM with " + str(total_bytes) + " bytes")

        # Enter programming mode before writing
        control_pin.value = False
        time.sleep(0.01)  # 10ms delay
        print_serial("Programming mode activated (GP2 set low)")
        
        # Start with dim blue LEDs during programming
        set_led_color(COLOR_DIM_BLUE)
        set_status_led(True)
        
        for i in range(0, total_bytes, page_size):
            # Get the data for this page
            page_end = min(i + page_size, total_bytes)
            page_data = all_bytes[i:page_end]
            
            # Calculate the actual EEPROM address for this page
            eeprom_addr = start_address + i
            
            # Write the page
            print_serial("Writing page at address 0x{:04X}".format(eeprom_addr))
            result = write_eeprom_page(EEPROM_ADDR, eeprom_addr, bytearray(page_data))
            
            if not result:
                print_serial("Error writing page at address 0x{:04X}".format(eeprom_addr))
                set_led_color(COLOR_OFF)
                set_status_led(False)
                return False
        
        # Programming complete - exit programming mode
        control_pin.value = True
        time.sleep(0.1)
        print_serial("Programming mode deactivated (GP3 set high)")
        
        # Print summary to match the header format
        filename_base = filename.split('/')[-1].split('.')[0]
        print_serial(filename_base + "[] = {")
        
        # Print 4 bytes per line
        for i in range(0, len(all_bytes), 4):
            line = ""
            for j in range(min(4, len(all_bytes) - i)):
                byte = all_bytes[i + j]
                line += "0x{:02X}, ".format(byte)
            print_serial(line)
        
        print_serial("};")
        print_serial("Total bytes programmed: " + str(total_bytes))
        print_serial("Start address: 0x{:04X}".format(start_address))
        print_serial("End address: 0x{:04X}".format(start_address + total_bytes - 1))
        
        # Special message for all.hex
        if base_filename == "all.hex":
            print_serial("ENTIRE EEPROM PROGRAMMED with all.hex")
        
        # Indicate file programming success with GREEN LEDs
        set_led_color(COLOR_GREEN)
        set_status_led(True)
        
        return True
    
    except Exception as e:
        print_serial("Error processing file: " + str(e))
        set_led_color(COLOR_OFF)
        set_status_led(False)
        return False

# Track processed files to avoid reprocessing
processed_files = set()
programming_complete = False

# Main program
print_serial("HEX File to EEPROM Programmer")
print_serial("Running on: " + board.board_id)
print_serial("I2C EEPROM address: 0x{:02X}".format(EEPROM_ADDR))
print_serial("WS2812 RGB LED on GP16 + Status LED on GP3:")
print_serial("  OFF = idle/waiting")
print_serial("  DIM BLUE = writing file")
print_serial("  GREEN = file write successful")
print_serial("  RED blinking = error/failure")
print_serial("Place .HEX files in the root directory to program the EEPROM")
print_serial("File to address mapping:")
# Sort files: numbered files first (0-7), then all.hex
sorted_files = sorted(FILE_ADDRESS_MAP.items(), key=lambda x: (x[0] != "all.hex", x[0]))
for file, addr in sorted_files:
    if file == "all.hex":
        print_serial("  {} -> 0x{:04X} (ENTIRE EEPROM - requires 1025 lines, 0x000-0xFFF)".format(file, addr))
    else:
        print_serial("  {} -> 0x{:04X} (requires 129 lines, 0x000-0x1FF)".format(file, addr))
print_serial("Default address for other files: 0x{:04X} (requires 129 lines, 0x000-0x1FF)".format(DEFAULT_START_ADDR))

# Try to initialize I2C and detect EEPROM
try:
    if not i2c.try_lock():
        print_serial("Could not lock I2C bus")
        # Blink both LEDs RED to indicate I2C error
        blink_led_pattern(COLOR_RED, 0.05, 0.05, 10)
    else:
        devices = i2c.scan()
        i2c.unlock()
        
        if EEPROM_ADDR in devices:
            print_serial("EEPROM detected at address 0x{:02X}".format(EEPROM_ADDR))
        else:
            print_serial("WARNING: EEPROM not detected at address 0x{:02X}".format(EEPROM_ADDR))
            print_serial("Available I2C devices: " + ", ".join(["0x{:02X}".format(addr) for addr in devices]))
            # Blink both LEDs RED to indicate EEPROM not found
            blink_led_pattern(COLOR_RED, 0.05, 0.05, 10)
except Exception as e:
    print_serial("I2C initialization error: " + str(e))
    try:
        i2c.unlock()  # Try to unlock in case it's already locked
    except:
        pass
    # Blink both LEDs RED to indicate error
    blink_led_pattern(COLOR_RED, 0.05, 0.05, 10)

# Make sure control pin is HIGH at startup
control_pin.value = True
print_serial("Control pin set HIGH at startup")

# Set both LEDs to OFF for startup
set_led_color(COLOR_OFF)
set_status_led(False)
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

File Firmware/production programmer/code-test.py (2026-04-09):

import os
import time
import board
import busio
import digitalio
import supervisor
import random
import neopixel
import displayio
import i2cdisplaybus
import terminalio
import adafruit_displayio_ssd1306
from adafruit_display_text import label

# Release any previously configured displays
displayio.release_displays()

# Set up I2C bus on GP0 (SDA) and GP1 (SCL)
i2c = busio.I2C(scl=board.GP1, sda=board.GP0)

# Set up OLED display
display_bus = i2cdisplaybus.I2CDisplayBus(i2c, device_address=0x3C)
display = adafruit_displayio_ssd1306.SSD1306(display_bus, width=128, height=32)

# OLED display group - 2 lines on 128x32
oled_group = displayio.Group()
oled_line1 = label.Label(terminalio.FONT, text="", color=0xFFFFFF, x=0, y=6)
oled_line2 = label.Label(terminalio.FONT, text="", color=0xFFFFFF, x=0, y=22)
oled_group.append(oled_line1)
oled_group.append(oled_line2)
display.root_group = oled_group

# Screensaver display group - single label "FV-1 PROG"
# terminalio.FONT is 6x12 pixels. "FV-1 PROG" = 9 chars = 54px wide, ~12px tall
# Bounce area: x in [0, 74], y in [6, 26]
screensaver_group = displayio.Group()
screensaver_label = label.Label(terminalio.FONT, text="FV-1 PROG", color=0xFFFFFF, x=0, y=16)
screensaver_group.append(screensaver_label)

# Screensaver / inactivity tracking
SCREENSAVER_TIMEOUT = 20  # 5 minutes in seconds
SCREENSAVER_MOVE_INTERVAL = 2.0  # seconds between position changes
last_activity_time = time.monotonic()
screensaver_active = False
last_screensaver_move = 0

def exit_screensaver():
    """Switch from screensaver back to normal display"""
    global screensaver_active
    if screensaver_active:
        screensaver_active = False
        display.root_group = oled_group

def reset_activity():
    """Reset the inactivity timer and exit screensaver if active"""
    global last_activity_time
    last_activity_time = time.monotonic()
    exit_screensaver()

def oled_status(line1, line2=""):
    """Update the OLED with two lines of status"""
    reset_activity()
    oled_line1.text = str(line1)[:21]  # ~21 chars fit at 6px wide on 128px
    oled_line2.text = str(line2)[:21]

# Set up control pin (GP2) - keep HIGH by default, toggle LOW only during programming
control_pin = digitalio.DigitalInOut(board.GP2)
control_pin.direction = digitalio.Direction.OUTPUT
control_pin.value = True  # Keep high by default

# Set up button on GP3 - momentary, active low with pull-up
button_pin = digitalio.DigitalInOut(board.GP3)
button_pin.direction = digitalio.Direction.INPUT
button_pin.pull = digitalio.Pull.UP
button_last_state = True  # pull-up means idle = True

# Set up WS2812 RGB LED on GP16
pixel = neopixel.NeoPixel(board.GP16, 1, brightness=1.0, auto_write=True, pixel_order='GRB')

# RGB Color definitions - solid colors only
COLOR_OFF = (0, 0, 0)       # Off
COLOR_RED = (255, 0, 0)     # Red for uploading
COLOR_GREEN = (0, 255, 0)   # Green for success
COLOR_BLUE = (0, 0, 255)    # Blue for idle state
COLOR_DIM_BLUE = (0, 0, 8)  # Very dim blue for programming

# EEPROM address
EEPROM_ADDR = 0x50

# Test mode: set to True to simulate programming without EEPROM hardware.
# Full flow runs with fake writes and realistic timing delays.
TEST_MODE = False

# File to EEPROM address mapping - only explicit slot files
FILE_ADDRESS_MAP = {
    "0.hex": 0x0000,
    "1.hex": 0x0200,
    "2.hex": 0x0400,
    "3.hex": 0x0600,
    "4.hex": 0x0800,
    "5.hex": 0x0A00,
    "6.hex": 0x0C00,
    "7.hex": 0x0E00,
}

# Default start address for single-slot files with unrecognized names
DEFAULT_START_ADDR = 0x0600

# Size constants for classification
SINGLE_SLOT_LINES = 129
FULL_EEPROM_LINES = 1025
SINGLE_SLOT_MIN_ADDR = 0x000
SINGLE_SLOT_MAX_ADDR = 0x1FF
FULL_EEPROM_MIN_ADDR = 0x000
FULL_EEPROM_MAX_ADDR = 0xFFF

# We'll use the normal REPL for output
def print_serial(message):
    """Print to the REPL"""
    print(message)

def set_led_color(color):
    """Set the WS2812 LED color"""
    pixel[0] = color
    
def blink_led_once(color, duration=0.2):
    """Blink both LEDs once quickly with specified color"""
    set_led_color(color)
    time.sleep(duration)
    set_led_color(COLOR_OFF)
    time.sleep(duration)

def blink_led_pattern(color, on_time=0.1, off_time=0.1, count=3):
    """Blink both LEDs in a pattern with specified color"""
    for _ in range(count):
        set_led_color(color)
        time.sleep(on_time)
        set_led_color(COLOR_OFF)
        time.sleep(off_time)

def parse_hex_line(line):
    """Parse a single line of Intel HEX format"""
    if not line.startswith(':'):
        return None, None, None, []
    
    # Remove the leading ':' and strip whitespace/newlines
    data = line.strip()[1:]
    
    try:
        # Get basic parameters
        byte_count = int(data[0:2], 16)
        address = (int(data[2:4], 16) << 8) + int(data[4:6], 16)
        record_type = int(data[6:8], 16)
        
        # Extract the data bytes
        byte_data = []
        for i in range(byte_count):
            pos = 8 + (i * 2)
            if pos + 2 <= len(data):
                byte_data.append(int(data[pos:pos+2], 16))
        
        return byte_count, address, record_type, byte_data
    
    except Exception as e:
        print_serial("Error parsing line: " + str(e))
        return None, None, None, []

def write_eeprom_page(eeprom_address, page_address, data):
    """Write a page of data to the EEPROM (max 32 bytes per page)"""
    if TEST_MODE:
        # Simulate write cycle timing
        time.sleep(0.006)
        return True
    
    # Create the I2C write buffer
    buffer = bytearray(2 + len(data))
    buffer[0] = (page_address >> 8) & 0xFF  # High byte of address
    buffer[1] = page_address & 0xFF         # Low byte of address
    buffer[2:] = data                       # Data bytes
    
    # Write to the EEPROM
    try:
        i2c.try_lock()
        i2c.writeto(eeprom_address, buffer)
        i2c.unlock()
        # Wait for write cycle to complete (6ms is sufficient for 24LC32A)
        time.sleep(0.006)  # 6ms
        
        return True
    except Exception as e:
        print_serial("EEPROM write error: " + str(e))
        try:
            i2c.unlock()  # Make sure to unlock even if there's an error
        except:
            pass
        return False
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

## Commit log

2025-08-06 Build 10
    Split assembler and examples into their own files
    added modal popups to prevent accidental clearing
    added note to editor window re: ascii only
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2025-08-08 UI changes
    Select 3.hex as default
    Clear assembly output window on editor clear or example load
2025-08-09 Build 13
    Added Download C Header button
    fixed issue with resolving skip targets
    fixed issue with S1_14 encoding
    fixed issue with register resolution
2025-08-13 Refactor RP2040 firmware
    Added complete fw blob UF2
    removed adafruit UF2 blob
    updated BOOT.PY for USB VID/PID info (preliminary, will change)
2025-08-13 Build 16
    Added clear hardware button
    Added serial connect button
    Added serial connect functions to ui.js
    Updated RP2040 code.py to ignore zero-byte hex files, prevents undesired updates at boot
    unified and cleaned CSS
    [code.py]
2025-08-16 Added fontsBuild 16
    debug_config.js: fixed issue with logging all data to console
    index.html: ui cleanup, match FXCore version
    - add user-preferences options
    - add set project folder button
    styles.css: added styling for project button
    ui.js: added project button handling
    - added user prefs settings for various toggles
    - replaced lots of clear calls with uodatedownloadbuttonstates()
2025-08-16 UI changes
    index.html: updated save and load functions, added project folder selection with better selector
    monaco.js added change detection stuff from fxcore
    styles.css removed custom styling for project folder select, no longer needed
    ui.js resolved issue with download picker
    - fixed download functions, now will land in same directory with correct filename
    - rework all load functions to fire modal and update teh hascontentchanged stuff
    code.py revert to last version from Friday, works great.
    [code.py]
2025-08-21 Build 17
    Incorporated flyout options + info
    Added instruction set reference
    Added keyboard shortcuts to match FXCore
    Fixed editor stealing shortcuts for assemble / download / clear
2025-08-21 Fix download button
    Needed to call updatedownloabuttonstatus() when selecting output directory
    fixed page title as set by Monaco (FV-1 Assembler *)
    removed references to FXCore
2025-09-24 Updated for v2e hardware (stereo + LED on GP3)
    Added second LED controls
2025-10-03 Add files via upload
    Bill of materials for hardware rev 2e PCBA
    [FV1_LC no jacks 2e_top_bom.csv]
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2025-10-05 Testing control pin changes
    Attempting to prevent weird noises during programming
    [code.py]
2025-10-07 Added gerbers and EAGLE files to Hardware folder
    [sandbox_jack_2c.GBL, sandbox_jack_2c.GBO, sandbox_jack_2c.GBP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]
2026-08-23 Add in-browser FV-1 simulator
    Runs an assembled program through a software model of the FV-1 at the
    chip's native 32768 Hz, so an algorithm can be auditioned without
    programming hardware. Adds a SIM flyout tab alongside OPTIONS/INFO/HELP.
    fv1-emu.js is the DSP core. It decodes the same 512-byte image that gets
    written to the EEPROM, using the bit layouts from generateMachineCode()
    in assembler.js, and executes 128 instructions per sample period.
    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
2026-08-23 Add register and reserved word reference to info flyout
    The info panel documented all 28 opcodes plus MEM and EQU, but nothing
    about the symbol table, so there was no way to look up what POT2 or
    COMPC actually mean without reading assembler.js.
    Adds two sections, REGISTERS and RESERVED, with values taken from
    initSymbolTable() in assembler.js rather than transcribed by hand:
    REGISTERS - the audio ins and outs, the three pots, REG0-31, ADDR_PTR
    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
2026-08-23 Track launch.json, ignore local Claude settings
    Adds the dev-server config that serves the Assembler folder over http on
    port 8777, which is how the app has to be run locally - opening
    index.html as a file:// page will not work. Per-user session state in
    .claude/settings.local.json stays out of the repo.
2026-08-23 Correct LFO rate and amplitude against AN-0001
    Reported symptom was that LFO rates sounded fast next to hardware. They
    were, by a factor of 2*pi, and there were two further problems behind it.
    Rate. Spin's application note AN-0001 gives Kf = 2^17 * (2*pi*f / R), so
    f = Kf * R / (2*pi * 2^17). The stored rate is already the angular step
    in radians per sample; multiplying it by 2*pi again made every sine LFO
    run 6.28 times too fast. The note states Kf 0..511 spans about 0 to 20 Hz,
    and its worked example, wlds SIN0,5,16384, is documented as "about
    0.2Hz" - that example now measures 0.199 Hz.
    Amplitude. The same example is documented as "+/-4096 samples for a
    total delay requirement of 8193"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
2026-08-23 Fix CHO interpolation and crossfade against AN-0001
    Reported symptom was pronounced amplitude modulation as the delay
    pointer wraps in a pitch shifter. Two errors in the CHO implementation.
    CHO RDA reads a single delay sample and scales it by a coefficient. The
    chip does not interpolate internally: a program issues two of these, at
    addr and addr+1 with COMPC on one of them, and that pair performs the
    linear interpolation AN-0001 describes as
    Sample[N]*(1-K) + Sample[N+1]*K
    The old code called an internal interpolator and then multiplied the
    result by the fraction again, applying K twice and modulating the
    amplitude at the ramp rate.
    The NA flag supplies a crossfade coefficient, and t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
2026-08-23 Add comment toggle shortcut, quarantine two invalid programs
    Registers a language configuration for the spin language declaring ';'
    as the line comment, plus bracket and quote pairs. Monaco already binds
    Cmd+/ (Ctrl+/ on Windows) to editor.action.commentLine; it did nothing
    here because only a Monarch tokens provider was registered, so the
    editor had no idea what a comment looks like in SpinASM. Toggling works
    on a multi line selection or on a single line with just the cursor.
    Moves faux-phaser.spn and shimmer-2.spn to files/known-bad/. Neither is
    an assembler bug - both contain invalid SpinASM that no FV-1 assembler
    will accept:
    faux-phaser.spn line 23 uses CHO RDAL,4, but the chip has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
2026-08-23 Read ramp LFOs at their true scale in CHO RDAL
    CHO RDAL normalised a ramp to full scale, so it returned 0 to 1.0 where
    hardware returns 0 to 0.5 for a 4096 sample ramp. The ramp accumulator
    counts position in 1/1024 sample steps and RDAL hands that raw count
    straight to ACC, so the value is position / 8192.
    Programs that build a triangle with "cho rdal / sof 1,-0.25 / absa" were
    saturating the accumulator for half of every cycle, leaving the sweep
    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
2026-08-23 Add a crystal selector to the simulator
    The FV-1's sample rate is its crystal frequency, and the emulator core is
    clocked by whatever rate the AudioContext runs at, so offering a choice of
    crystal is mostly a matter of letting the selection reach the constructor.
    Nine presets from 8.192 kHz to 64 kHz, stock 32.768 kHz by default, with the
    resulting maximum delay time and Nyquist shown alongside.
    AudioContext.sampleRate is fixed at construction, so a change tears the
    engine down and rebuilds it, restarting playback if it was running. Loaded
    audio files keep their undecoded bytes and are decoded again at the new
    rate: decodeAudioData resamples to the context rate and detaches the buffer
    it is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
2026-08-24 Name the simulator pots from the program source
    A pot called "Delay time" is easier to reach for than POT0, so the
    simulator now takes its pot labels from a tag in the source, the same
    way the FXCore editor does:
    ; #POT0 Delay time
    The tag is read from the comment part of a line, so it can never
    collide with code and the assembler never sees it. Labels follow the
    editor as you type, not only on a build, and a renamed pot keeps its
    hardware name in the row tooltip. An untagged pot stays POT0-POT2.
    The bundled delay, chorus and tremolo examples use the tags, and the
    tremolo now runs both channels rather than only the left.
2026-08-24 Drive the simulator from a MIDI controller
    CC50-52 move POT0-POT2 and CC102 switches bypass, so a program can
    be auditioned with the same knobs that will play it on the pedal.
    Pot values now live in the simulator rather than in the sliders: a
    slider only has 100 steps, which would have thrown away a quarter of
    the resolution MIDI sends. The sliders and readouts are redrawn on
    the next frame, but the value reaches the core straight away, so the
    sound keeps up in a backgrounded tab where no frame ever arrives.
    Bypass ramps its gains instead of jumping, which was clicking.
    The panel had grown taller than most windows, so its spacing is
    tightened and its prose moved into the help tab. Panels a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
2026-08-25 Match the FXCore simulator panel
    The two assemblers ship the same simulator, so it should be the same
    panel. Rebuild the FV-1 one from the FXCore Test Drive panel's markup and
    CSS: transport, status and program state at the top, then Outputs,
    Clock, Source, Pots, Levels and MIDI as flat rows rather than the nested
    label-in-.options structure it had. The FV-1 has three pots where the
    FXCore has six plus a switch bank, so the rows here keep more room --
    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
2026-08-25 Latch PACC per instruction, not per sample period
    PACC was only assigned at the end of the sample loop, never inside step(), so
    WRHX, WRLX and SKP ZRC read the previous sample's final accumulator instead of
    the previous instruction's entry value. Single-pole shelving filters -- common
    throughout FV-1 reverbs and tone stacks -- came out wrong as a result, and ZRC
    could only ever detect a zero crossing between samples.
    Spin's architecture overview calls PACC "the previous instruction's value", and
    the note "Previous ACC value is simultaneously loaded into PACC" appears on every
    instruction that writes ACC. It is absent only from SKP, WLDS, WLDR and JAM,
    none of which touch the accumulator. Th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
2026-08-25 Assemble the LOG offset as S.10, matching the simulator and asfv1
    LOG routed its offset through parseS4_6 while SOF and EXP used parseS_10, so
    `log 1.0, -0.5` was encoded at sixteen times the intended scale. The simulator
    decoded it the same way, so the pair agreed with each other and both differed
    from asfv1, which parses all three offsets as S.10 -- and from Spin's reference,
    which gives this constant as -1.0 to +0.999.
    The previous commit corrected the simulator alone, which left the round trip
    broken: the assembler still wrote S4.6 while the simulator had started reading
    S.10. This completes the change.
    Adds spin-test/roundtrip-test.js (npm run test:roundtrip), which exercises the
    asse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
2026-08-25 Start the next delay block one past the previous one's top
    `mem x N` spans base..base+N inclusive, which is N+1 locations -- one more than
    the declared length, so a block has room for both a read and a write pointer.
    The next block therefore starts at top+1, not at top. FXCore's .mem documents the
    same rule explicitly, and asfv1 allocates the same way.
    Without the +1, `x#` and the next block's head are the same address, so writing
    the next block overwrites what the earlier block's tail reads. For
    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
2026-08-25 Round coefficients to nearest instead of truncating
    Every fixed-point conversion floored, at thirteen of fourteen sites, with one
    rounding -- so the assembler was not consistent with itself. Flooring biases each
    fractional coefficient down by half an LSB on average, about -0.4997 against
    round's -0.0008, which is a systematic offset rather than noise. One LSB of S1.9
    is 1.95e-3, so all-pass and delay coefficients landed roughly 0.1% low.
    asfv1 scales with Python's round() at all six of its sites, and Python breaks
    ties to even where Math.round breaks them away from zero. That only shows up when
    a value lands exactly on .5 -- `rda 100, 0.0009765625` is half an S1.9 LSB, where
    asfv1 gives 0 a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
2026-08-25 Round the ADC input rather than truncating
    The float test signal was floored on its way to a 24-bit sample, which biases
    every input down by half an LSB on average where rounding leaves the error
    centred on zero. This is a model boundary rather than chip behaviour -- a real
    ADC hands over an integer and there is no float to convert -- but the bias is
    free to remove and it makes this model agree bit for bit with an independent one.
    Found by differential testing: 300 randomised programs covering every mnemonic
    were run through this simulator and through a separately written model, and 18
    of them differed by up to 1764 LSB. With the input conversions matched the two
    agree exactly, with no roun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
2026-09-02 Add the FV-2040 extended instruction set behind a #extended pragma
    The FV-2040 runs a strict superset of the FV-1's instruction set: sixteen
    address bits instead of fifteen, so 65536 words of delay; RMPAX, which reads
    ADDR_PTR as ACC[22:7] and so can point anywhere in that tank; and POT3-POT5
    at registers 0x19-0x1b. Every extended word is a legal FV-1 word with a bit
    set that an FV-1 ignores, so nothing here changes what an existing program
    assembles to - the 164-file corpus in spin-test/files is byte-identical.
    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
2026-09-03 Add RAND and four more LFOs to #extended
    Two additions to the extended instruction set, both in space the FV-1
    left unclaimed.
    RAND takes opcode 21: the FV-1 assigns 0-20, so a legacy image cannot
    hold this value, which is a firmer claim than any spare bit inside a
    field. It is field for field a RDAX -- register at 10:5, S1.14
    coefficient at 31:16 -- so the assembler and the decoder share an operand
    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
2026-09-03 Stop #extended widening the WLDS amplitude
    The WLDS amplitude read through parseDelayAddress, whose ceiling
    enableExtended raises from 0x7FFF to 0xFFFF. But amplitude fills bits
    5-19 and rate 20-28, so WLDS has no spare bit to widen into: the field
    is 15 bits with or without the pragma.
    So `wlds SIN0, 26, 40000` was an error without the pragma and assembled
    with it, masked down to 7232 in generateMachineCode -- the pragma turned
    a diagnostic into silent truncation. The error it replaced was also
    misleading, offering a "#extended reaches 16 bit addresses" hint that is
    true of RDA/WRA/WRAP and not of this operand.
    asfv1-extended already splits these two parsers for this exact reason,
    and nam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
2026-09-04 Fix five defects found reviewing the simulator branch
    compress() masked the delay RAM magnitude with 0x7FFFFF, which turned
    -0x800000 -- the exact value clamp24() returns on every negative overflow
    -- into zero. A negatively clipped peak was stored as silence rather than
    -1.0, so a hard-driven delay or reverb tank dropped out instead of
    clipping. Clamp the magnitude instead; 0x800000 still encodes cleanly as
    exponent 7 with a mantissa of 256.
    simInitEngine() never sent the current pot positions to the worklet it
    had just built, so the core fell back to its own 0.5 default. A pot moved
    before Play, or any crystal change, left the sliders and the DSP showing
    different values.
    simConnectSourc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
2026-09-04 Fix silent mis-assembly of hex literals and blank CHO flags
    Assembling every program in spin-test/files with both this assembler and
    asfv1 and diffing the images put 18 of 141 files apart. Two causes, both
    silent -- no error, no warning, just different machine code:
    'e' is a hex digit as well as a float exponent marker, and the scanner
    tested for it before the radix prefix, so 0x0E and 0xFFFE00 went down the
    float path where parseFloat() stops at the 'x' and returns 0. Four corpus
    programs hit it: rom_chor_rev.spn, rom_fla_rev.spn and rom_trem_rev.spn
    each lost the flags off a `cho RDA,SIN0,0x0E,...`, and afx_reverse_delay's
    `or 0xFFFE00` assembled as `or 0`.
    An omitted CHO flags field ret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
2026-09-04 Match the app to its own options, and emit a C header that compiles
    The hidden clampOption and spinRealsOption checkboxes were created
    unticked, so the browser assembled with clamp and spinreals off while
    spin-test -- and the comment in roundtrip-test.js claiming the app enables
    both -- assembled with them on. Nothing in the corpus depended on it, but
    an out-of-range coefficient was a hard error in the app where SpinASM and
    asfv1 -c both clamp and warn. Tick both, so the app, its tests and asfv1
    agree on what a program means.
    toCHeader() emitted `NAME[] = {`, with no type and with the name taken
    raw from the filename, so bass-fv1-p2-delay.h produced
    `BASS-FV1-P2-DELAY_DATA[] = {` -- neither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
2026-09-04 Assemble the extended instruction set behind #extended
    The FV-2040 runs the FV-1 instruction set on an RP2040, where the
    constraints that made sense in silicon in 1999 are off, and
    asfv1-extended assembles for it. This is the same extension, ported:
    Delay address 15 bits / 32768 -> 16 bits / 65536, via bit 20
    MEM pool 32767 -> 65535
    Pots POT0-POT2 -> + POT3-POT5 at 0x19-0x1b
    Indirect read RMPA (ACC[23:8]) -> + RMPAX (ACC[22:7]), bit 5
    Noise none -> RAND, opcode 21, RDAX operands
    LFOs SIN0-1, RMP0-1 -> + SIN2-3, RMP2-3, regs 0x08-0x0f
    None of it exists unless the source carries a '#extended'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
2026-09-04 Document the extended set, and ask before writing one to hardware
    The reference gains an EXTENDED section -- the pragma, RMPAX, RAND, the
    wider address and MEM pool, POT3-POT5, and the four new LFOs -- and the
    help flyout a matching prose section. Both appear only while the source
    carries '#extended' and go away again when the line is deleted. Every one
    of these instructions is an error in a program that has not asked for
    them, so showing them to someone writing FV-1 code is worse than not
    having them at all.
    They follow the editor rather than the last successful build: you look an
    instruction up before you can assemble it. FV1Assembler.isExtendedSource()
    is now the one place that decides w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
2026-09-04 Delete dead code, and correct the vendored asfv1 licence header
    downloadHexToHardware() was a byte-for-byte duplicate of downloadHex()
    with no callers -- and, since the last commit, the one without the
    extended-image guard, so wiring it up by accident would have skipped the
    warning.
    The simulator's AnalyserNode sat in the audio graph between the output gain
    and the destination and was never read: no spectrum display uses it, and
    nothing calls getByteFrequencyData. The graph now goes straight to the
    destination. simMeterTimer was declared and never used; the meter is
    driven by messages from the worklet.
    ASFV1 Source/asfv1.py carried a GPL-3 block while ThirdPartyNotices.txt
    credits asfv1 as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
2026-09-04 Build 20, and make the extended note say something true
    The line under the pots read "POT3-POT5 need #extended" but was shown only
    when simExtended was set -- so it appeared exactly where it was untrue,
    beside the three sliders it claimed were unavailable, and was hidden in the
    stock case where it would have explained anything. It could never be seen
    usefully, which is why it looked as though it had gone.
    It now says what is actually true when it is shown: the extension is
    active, and here is what that bought. Kept on the extended side rather
    than flipped to the stock one, because three sliders appearing out of
    nowhere wants a word beside them, while three sliders not being there is
    just an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
2026-09-05 Keep the extended instruction set out of the documentation
    It stays in the assembler, the simulator and the tests, and it is still
    reached the same way: a source line reading '#extended'. What changes is
    that nothing says so unless a program has already asked.
    The reference section and the help panel that describe it were already
    gated on the pragma and follow the editor, so they were never the problem.
    Everything else was: the readme carried a section naming the target
    hardware and tabulating the encoding, help.html listed RAND and RMPAX
    beside the ordinary opcodes and named the four extra LFOs, and the
    simulator's own help described POT3-POT5, the extra CCs and the wider
    tank whether or n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
2026-09-05 Programs of 256 instructions, in the assembler and the core
    The FV-1 runs 128 instructions every sample whether a program uses them or
    not, so on the chip the length IS the budget. Off it the two come apart:
    a skip skips, padding is never reached, and what is left of 128 is a
    container. #extended raises that container to 256, which is two program
    slots -- the unit a bank file already divides into.
    assembler.js follows asfv1-extended, as it does everywhere else: proglen
    is 128 until the pragma raises it, and generateMachineCode sizes the image
    from the program rather than from a constant. A source with the pragma
    and 128 instructions or fewer still assembles to exactly the 512 bytes it
    di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
2026-09-08 Clock the core separately from the audio graph
    The crystal control tore the engine down on every change, because that is
    what an AudioContext requires: its sampleRate is fixed at construction, so
    the only way to run the core at 16 kHz was to build a 16 kHz context. Every
    change was therefore a power cycle -- delay memory cleared, and whatever was
    feeding the input started again from the top. That made the control
    impossible to sweep and, with an audio file selected, impossible to use
    without losing your place in it.
    So the graph now opens at the device's own rate and stays there, and
    FV1Clock converts between that and the crystal. Changing the crystal is a
    message to the worklet: the contex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
2026-09-08 Follow the editor for the extended set, not the last build
    Everything about the extended instruction set is meant to stay out of sight
    until a program asks for it. Two places were still showing it, and one of
    them could not be reached at all.
    The simulator panel gated POT3-POT5 on assembledExtended, which assemble()
    only sets inside its success branch. That is a chicken and egg: a source
    that reads POT3 does not assemble until the pragma is there, so the slider
    for the pot you are writing the program to read never appeared. The way
    through was to assemble once with the pragma and nothing else, then add the
    instructions -- which is not a workflow, it is a bug with a workaround.
    So the panel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
2026-09-08 Version the script and stylesheet URLs
    Nothing here is served with a Cache-Control header, so a browser is free to
    go on running the copy it already has, and Chrome does: a stale monaco.js
    survived several ordinary reloads while I was working on the tokenizer, and
    the page ran the old file while the server had the new one. It cost an hour
    to notice, because a cached script does not fail -- it just quietly is not
    the code you are reading.
    The worse case is not a missed update but a partial one. Files expire
    independently, so a returning visitor gets some of the new build and some of
    the old, and the app breaks in ways that make no sense against either.
    So each local script and the styleshee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

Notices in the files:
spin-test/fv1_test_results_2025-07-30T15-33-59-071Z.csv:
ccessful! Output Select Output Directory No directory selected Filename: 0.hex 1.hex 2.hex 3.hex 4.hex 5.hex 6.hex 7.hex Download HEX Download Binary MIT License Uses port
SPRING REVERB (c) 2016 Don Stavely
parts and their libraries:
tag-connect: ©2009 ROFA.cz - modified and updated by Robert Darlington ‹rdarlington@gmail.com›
